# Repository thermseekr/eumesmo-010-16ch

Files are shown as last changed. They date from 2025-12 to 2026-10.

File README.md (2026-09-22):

# eumesmo-010-16ch
ESP32 based board with 16x 0-10V analog output, for light dimming control. The board has a DC-DC Converter and an I2C isolator to keep the digital and analog domains fully separated.

The board is compatible with the SP7 DIN rail system from Metaltex.

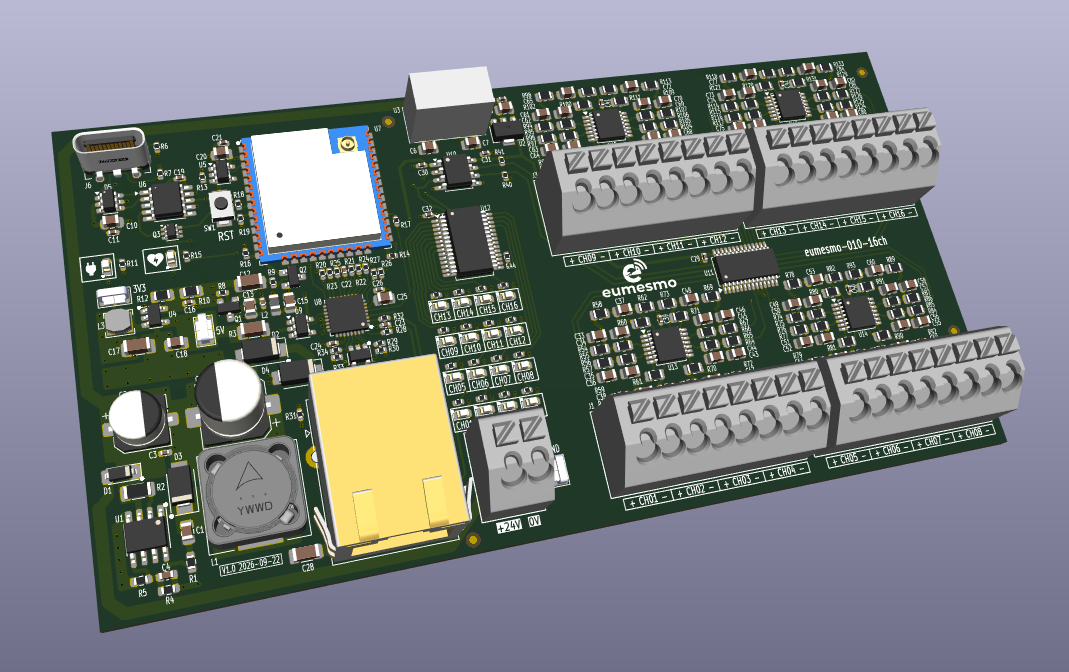
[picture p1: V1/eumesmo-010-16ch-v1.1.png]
eumesmo-010-16ch


## VERSION HISTORY
2026-09-22 V1.0 - RJ45 jack and terminal blocks repositioned inwards the board to make space for the PCB holder. ETH tracks rerouted for better EMC.

2026-07-02 V1.0 - Initial release.

## LICENSE

This project is licensed under the [Creative Commons BY-NC 4.0 License](https://creativecommons.org/licenses/by-nc/4.0/).
Commercial use is not permitted without prior written consent. See the [LICENSE.txt](LICENSE.txt) file for details.

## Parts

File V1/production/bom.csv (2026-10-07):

Designator | Footprint | Quantity | Value | LCSC Part #
C1, C33, C34, C35, C36, C43, C44, C45, C46, C49, C50, C51, C52, C55, C56, C57, C58, C61, C62, C63, C64, C67, C68, C69, C70, C73, C74, C75, C76, C79, C80, C81, C82 | 0805 | 33 | 100nF/100V | C28233
C10, C13, C15, C18, C20, C7 | 0805 | 6 | 10uF/25V | C15850
C11, C14, C19, C21, C22, C23, C24, C27, C29, C3, C30, C31, C32, C39, C40, C41, C42, C9 | 0402 | 18 | 100nF/50V | C307331
C12, C17 | 1206 | 2 | 22uF/10V | C5672
C16 | 0402 | 1 | 22pF/50V | C1555
C2 | CP_Elec_6.3x5.4 | 1 | 47uF/35V | C129415
C25, C6, C8 | 0805 | 3 | 1uF/50V | C28323
C26 | 0402 | 1 | 470pF/50V | C1537
C28 | 1206 | 1 | 1nF/2kV | C9196
C37, C38, C47, C48, C53, C54, C59, C60, C65, C66, C71, C72, C77, C78, C83, C84 | 0805 | 16 | 100pF/50V | C1790
C4 | 0603 | 1 | 12pF/50V | C38523
C5 | CP_Elec_8x10.5 | 1 | 470uF/16V | C96179
D1 | D_SOD-123 | 1 | SM4007PL | C64898
D10, D11, D12, D13, D14, D15, D16, D17, D18, D19, D20, D21, D22, D23, D24, D6, D7, D9 | 0603 | 18 | ORANGE/0603 | C2987557
D2, D4 | D_SMA | 2 | SS34 | C8678
D3 | D_SMA | 1 | SS510 | C65010
D5 | SOT-23-6 | 1 | USBLC6-2SC6 | C7519
D8 | SOT-23-5 | 1 | ESDS314DBV | C1847859
J1, J2, J3, J4 | TerminalBlock_Wago_250-208_1x08_P3.5mm_45Degree | 4 | 250-208 | C2833587
J5 | TerminalBlock_Wago_250-202_1x02_P3.5mm_45Degree | 1 | 250-202 | C2765061
J6 | USB_C_Receptacle_ShouHan_TYPE-C-16PLT-H10.0 | 1 | USB_C_Receptacle_USB2.0 | C3151749
J7 | RJ45_HanRun_HR915340A | 1 | ETHERNET | C6674467
L1 | L_12x12mm_H6mm | 1 | 33uH 2,1A | C169386
L2 | 0805 | 1 | 2A 600R | C139168
L3 | L_3x3mm_H1.5mm | 1 | 2,2uH 1,5A | C370424
Q1 | SOT-23 | 1 | WPM2015-3/TR | C558305
Q2 | SOT-23 | 1 | MMUN2211LT3G | C150229
Q3 | SOT-363_SC-70-6 | 1 | UMH3N | C62892
R1 | 0603 | 1 | 5,1R/100mW | C25197
R10 | 0805 | 1 | 100k/125mW | C149504
R100, R101, R110, R111, R120, R121, R130, R131, R60, R61, R70, R71, R80, R81, R90, R91 | 0805 | 16 | 11k/125mW | C17429
R102, R103, R104, R105, R106, R107, R112, R113, R114, R115, R116, R117, R122, R123, R124, R125, R126, R127, R132, R133, R54, R55, R56, R57, R62, R63, R64, R65, R66, R67, R72, R73, R74, R75, R76, R77, R82, R83, R84, R85, R86, R87, R92, R93, R94, R95, R96, R97 | 0805 | 48 | 10k/125mW | C17414
R108, R109, R118, R119, R128, R129, R58, R59, R68, R69, R78, R79, R88, R89, R98, R99 | 0805 | 16 | 47R/125mW | C17714
R11, R15, R35, R36, R37, R38, R39, R42, R43, R45, R46, R47, R48, R49, R50, R51, R52, R53 | 0402 | 18 | 680R | C25130
R12 | 0805 | 1 | 22,1k/125mW | C17552
R13, R14, R16, R8 | 0402 | 4 | 10k | C25744
R17 | 0402 | 1 | 33R | C25105
R18, R19, R21, R22, R23, R24, R25, R26, R27, R40, R41 | 0402 | 11 | 2,2k | C25879
R2 | 1206 | 1 | 30mR/333mW | C473665
R20 | 0402 | 1 | 1.5k | C25867
R28 | 0402 | 1 | 12,1k | C281773
R29, R30, R33, R34 | 0402 | 4 | 49,9R | C25120
R3 | 1206 | 1 | 0,1R | C309528
R31, R32 | 0402 | 2 | 330R | C25104
R4 | 0603 | 1 | 300k/100mW | C23024
R44, R9 | 0402 | 2 | 1k | C11702
R5 | 0603 | 1 | 52,3k/100mW | C23198
R6, R7 | 0402 | 2 | 5,1k | C105872
SW1 | SW_SPST_Xunpu_TS1088AR02016 | 1 | RESET | C720477
TP2, TP3, TP8 | TestPoint_Keystone_5019_Miniature | 3 | TP5019 | C238131
U1 | SOIC-8-1EP_3.9x4.9mm_P1.27mm_EP2.41x3.81mm_ThermalVias | 1 | TX4138 | C329267
U10 | SOIC-8_3.9x4.9mm_P1.27mm | 1 | ISO1540 | C179739
U11 | TSSOP-28_4.4x9.7mm_P0.65mm | 1 | PCA9685PW | C2678753
U12 | SSOP-28_5.3x10.2mm_P0.65mm | 1 | MCP23017 | C506653
U13, U14, U15, U16 | TSSOP-14_4.4x5mm_P0.65mm | 4 | TLV274 | C9914
U2 | SOT-89-3 | 1 | L78L05_SOT89 | C42738
U3 | Ylptec BxxxxS-1WR3 | 1 | B2412S-1WR3 | C5369469
U4 | SOT-23-5_Shorter_Pins | 1 | SY8089A1AAC | C479074
U5, U9 | SOT-23-5 | 2 | TPS3820-33 | C130064
U6 | SSOP-10-1EP_3.9x4.9mm_P1mm_EP2.1x3.3mm | 1 | CH340K | C968586
U7 | ESP32-WROOM-32U | 1 | ESP32-WROOM-32UE-N16 | C701346
U8 | QFN-32-1EP_5x5mm_P0.5mm_EP3.3x3.3mm_ThermalVias | 1 | LAN8710A | C46185

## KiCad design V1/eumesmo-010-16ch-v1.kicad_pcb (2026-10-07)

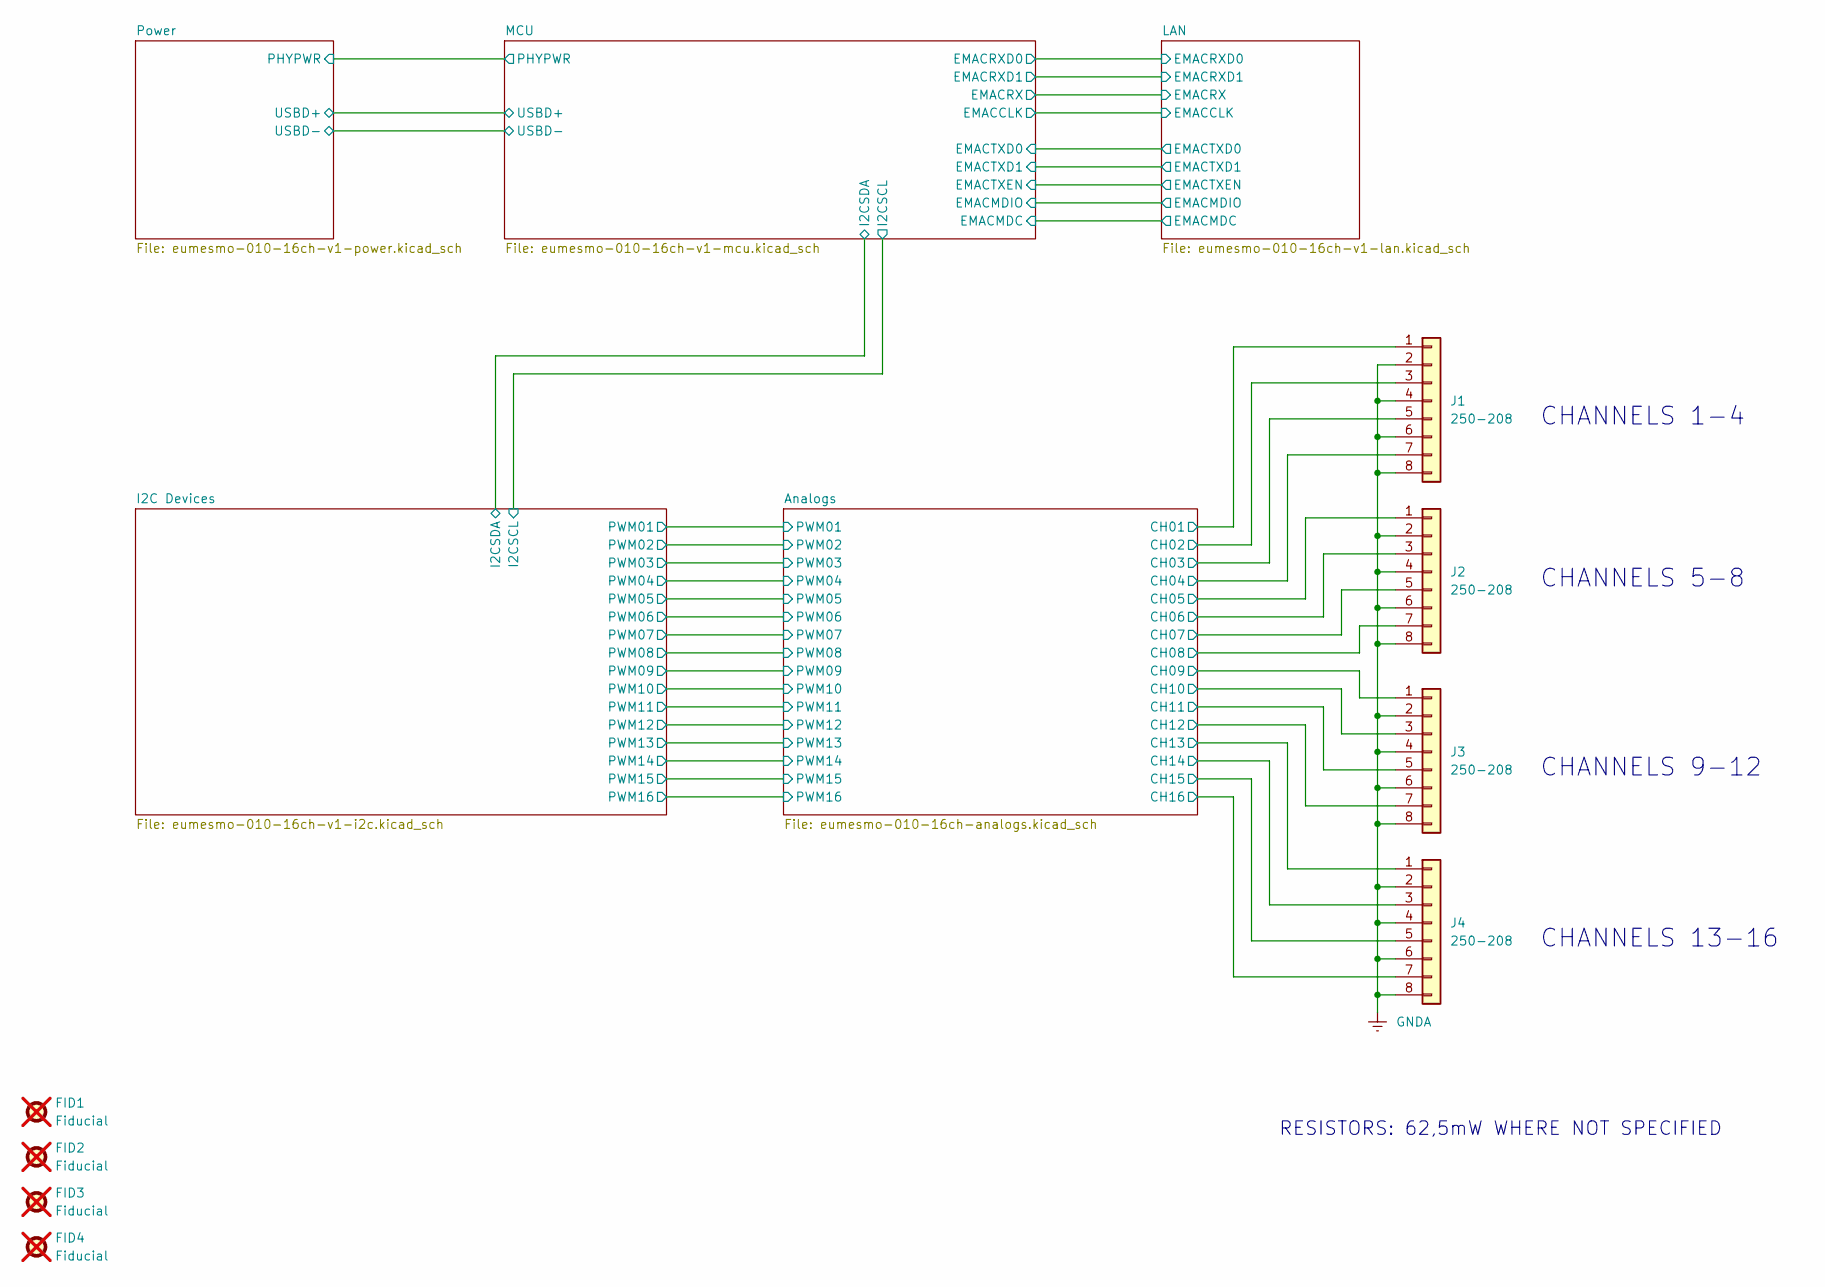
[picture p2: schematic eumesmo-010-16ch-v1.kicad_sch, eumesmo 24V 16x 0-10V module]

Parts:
FID1, FID2, FID3, FID4: Fiducial; Fiducial_1mm_Mask2mm; not fitted
J1, J2, J3, J4: 250-208; TerminalBlock_Wago_250-208_1x08_P3.5mm_45Degree; Mfr PN 250-208; LCSC Part # C2833587

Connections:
/Analogs/CH01: J1.1; also elsewhere on the board
/Analogs/CH02: J1.3; also elsewhere on the board
/Analogs/CH03: J1.5; also elsewhere on the board
/Analogs/CH04: J1.7; also elsewhere on the board
/Analogs/CH05: J2.1; also elsewhere on the board
/Analogs/CH06: J2.3; also elsewhere on the board
/Analogs/CH07: J2.5; also elsewhere on the board
/Analogs/CH08: J2.7; also elsewhere on the board
/Analogs/CH09: J3.1; also elsewhere on the board
/Analogs/CH10: J3.3; also elsewhere on the board
/Analogs/CH11: J3.5; also elsewhere on the board
/Analogs/CH12: J3.7; also elsewhere on the board
/Analogs/CH13: J4.1; also elsewhere on the board
/Analogs/CH14: J4.3; also elsewhere on the board
/Analogs/CH15: J4.5; also elsewhere on the board
/Analogs/CH16: J4.7; also elsewhere on the board
GNDA: J1.2, J1.4, J1.6, J1.8, J2.2, J2.4, J2.6, J2.8, J3.2, J3.4, J3.6, J3.8, J4.2, J4.4, J4.6, J4.8; also elsewhere on the board

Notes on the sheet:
CHANNELS 9-12
CHANNELS 13-16
RESISTORS: 62,5mW WHERE NOT SPECIFIED
CHANNELS 1-4
CHANNELS 5-8

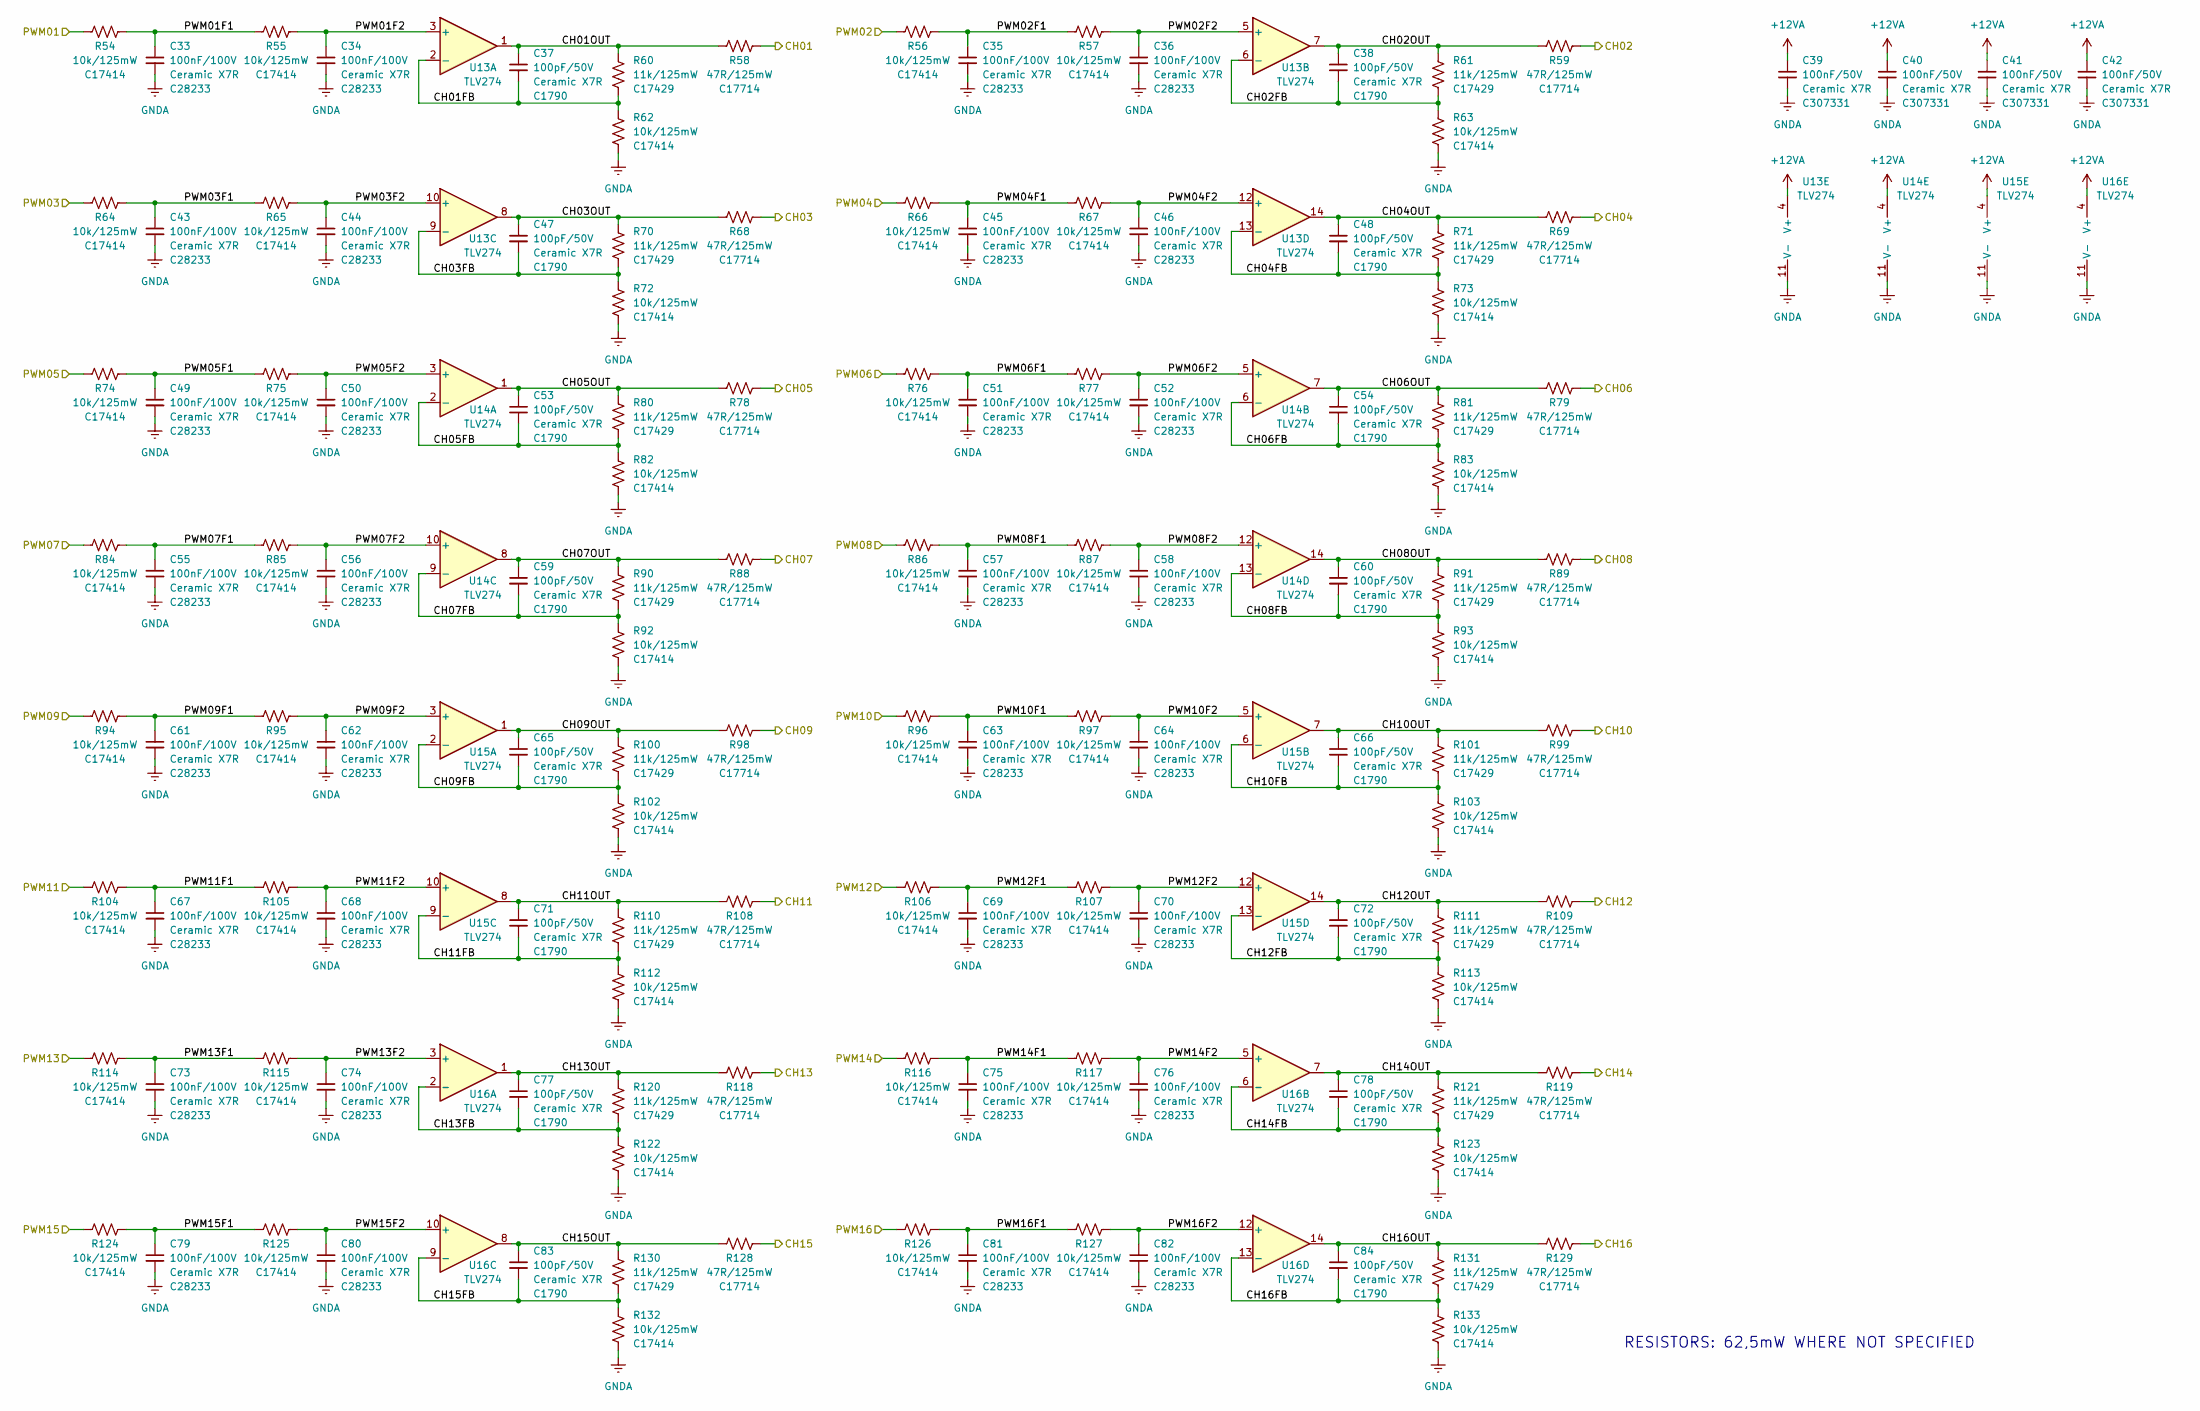
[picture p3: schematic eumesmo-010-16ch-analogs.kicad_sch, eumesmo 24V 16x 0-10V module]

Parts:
C33, C34, C35, C36, C43, C44, C45, C46, C49, C50, C51, C52, C55, C56, C57, C58, C61, C62, C63, C64, C67, C68, C69, C70, C73, C74, C75, C76, C79, C80, C81, C82: 100nF/100V; C_0805_2012Metric; Mfr PN CL21B104KCFNNNE; LCSC Part # C28233
C37, C38, C47, C48, C53, C54, C59, C60, C65, C66, C71, C72, C77, C78, C83, C84: 100pF/50V; C_0805_2012Metric; Mfr PN CL21C101JBANNNC; LCSC Part # C1790
C39, C40, C41, C42: 100nF/50V; C_0402_1005Metric; Mfr PN CL05B104KB54PNC; LCSC Part # C307331
R54, R55, R56, R57, R62, R63, R64, R65, R66, R67, R72, R73, R74, R75, R76, R77, R82, R83, R84, R85, R86, R87, R92, R93, R94, R95, R96, R97, R102, R103, R104, R105, R106, R107, R112, R113, R114, R115, R116, R117, R122, R123, R124, R125, R126, R127, R132, R133: 10k/125mW; R_0805_2012Metric; Mfr PN 0805W8F1002T5E; LCSC Part # C17414
R58, R59, R68, R69, R78, R79, R88, R89, R98, R99, R108, R109, R118, R119, R128, R129: 47R/125mW; R_0805_2012Metric; Mfr PN 0805W8F470JT5E; LCSC Part # C17714
R60, R61, R70, R71, R80, R81, R90, R91, R100, R101, R110, R111, R120, R121, R130, R131: 11k/125mW; R_0805_2012Metric; Mfr PN 0805W8F1102T5E; LCSC Part # C17429
U13, U14, U15, U16: TLV274; TSSOP-14_4.4x5mm_P0.65mm; Mfr PN TLV274; LCSC Part # C9914

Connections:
+12VA: C39.1, C40.1, C41.1, C42.1, U13.4 (V+), U14.4 (V+), U15.4 (V+), U16.4 (V+); also elsewhere on the board
/Analogs/CH01: R58.2; also elsewhere on the board
/Analogs/CH01FB: C37.2, R60.1, R62.2, U13.2 (-)
/Analogs/CH01OUT: C37.1, R58.1, R60.2, U13.1
/Analogs/CH02: R59.2; also elsewhere on the board
/Analogs/CH02FB: C38.2, R61.1, R63.2, U13.6 (-)
/Analogs/CH02OUT: C38.1, R59.1, R61.2, U13.7
/Analogs/CH03: R68.2; also elsewhere on the board
/Analogs/CH03FB: C47.2, R70.1, R72.2, U13.9 (-)
/Analogs/CH03OUT: C47.1, R68.1, R70.2, U13.8
/Analogs/CH04: R69.2; also elsewhere on the board
/Analogs/CH04FB: C48.2, R71.1, R73.2, U13.13 (-)
/Analogs/CH04OUT: C48.1, R69.1, R71.2, U13.14
/Analogs/CH05: R78.2; also elsewhere on the board
/Analogs/CH05FB: C53.2, R80.1, R82.2, U14.2 (-)
/Analogs/CH05OUT: C53.1, R78.1, R80.2, U14.1
/Analogs/CH06: R79.2; also elsewhere on the board
/Analogs/CH06FB: C54.2, R81.1, R83.2, U14.6 (-)
/Analogs/CH06OUT: C54.1, R79.1, R81.2, U14.7
/Analogs/CH07: R88.2; also elsewhere on the board
/Analogs/CH07FB: C59.2, R90.1, R92.2, U14.9 (-)
/Analogs/CH07OUT: C59.1, R88.1, R90.2, U14.8
/Analogs/CH08: R89.2; also elsewhere on the board
/Analogs/CH08FB: C60.2, R91.1, R93.2, U14.13 (-)
/Analogs/CH08OUT: C60.1, R89.1, R91.2, U14.14
/Analogs/CH09: R98.2; also elsewhere on the board
/Analogs/CH09FB: C65.2, R100.1, R102.2, U15.2 (-)
/Analogs/CH09OUT: C65.1, R98.1, R100.2, U15.1
/Analogs/CH10: R99.2; also elsewhere on the board
/Analogs/CH10FB: C66.2, R101.1, R103.2, U15.6 (-)
/Analogs/CH10OUT: C66.1, R99.1, R101.2, U15.7
/Analogs/CH11: R108.2; also elsewhere on the board
/Analogs/CH11FB: C71.2, R110.1, R112.2, U15.9 (-)
/Analogs/CH11OUT: C71.1, R108.1, R110.2, U15.8
/Analogs/CH12: R109.2; also elsewhere on the board
/Analogs/CH12FB: C72.2, R111.1, R113.2, U15.13 (-)
/Analogs/CH12OUT: C72.1, R109.1, R111.2, U15.14
/Analogs/CH13: R118.2; also elsewhere on the board
/Analogs/CH13FB: C77.2, R120.1, R122.2, U16.2 (-)
/Analogs/CH13OUT: C77.1, R118.1, R120.2, U16.1
/Analogs/CH14: R119.2; also elsewhere on the board
/Analogs/CH14FB: C78.2, R121.1, R123.2, U16.6 (-)
/Analogs/CH14OUT: C78.1, R119.1, R121.2, U16.7
/Analogs/CH15: R128.2; also elsewhere on the board
/Analogs/CH15FB: C83.2, R130.1, R132.2, U16.9 (-)
/Analogs/CH15OUT: C83.1, R128.1, R130.2, U16.8
/Analogs/CH16: R129.2; also elsewhere on the board
/Analogs/CH16FB: C84.2, R131.1, R133.2, U16.13 (-)
/Analogs/CH16OUT: C84.1, R129.1, R131.2, U16.14
/Analogs/PWM01: R54.1; also elsewhere on the board
/Analogs/PWM01F1: C33.1, R54.2, R55.1
/Analogs/PWM01F2: C34.1, R55.2, U13.3 (+)
/Analogs/PWM02: R56.1; also elsewhere on the board
/Analogs/PWM02F1: C35.1, R56.2, R57.1
/Analogs/PWM02F2: C36.1, R57.2, U13.5 (+)
/Analogs/PWM03: R64.1; also elsewhere on the board
/Analogs/PWM03F1: C43.1, R64.2, R65.1
/Analogs/PWM03F2: C44.1, R65.2, U13.10 (+)
/Analogs/PWM04: R66.1; also elsewhere on the board
/Analogs/PWM04F1: C45.1, R66.2, R67.1
/Analogs/PWM04F2: C46.1, R67.2, U13.12 (+)
/Analogs/PWM05: R74.1; also elsewhere on the board
/Analogs/PWM05F1: C49.1, R74.2, R75.1
/Analogs/PWM05F2: C50.1, R75.2, U14.3 (+)
/Analogs/PWM06: R76.1; also elsewhere on the board
/Analogs/PWM06F1: C51.1, R76.2, R77.1
/Analogs/PWM06F2: C52.1, R77.2, U14.5 (+)
/Analogs/PWM07: R84.1; also elsewhere on the board
/Analogs/PWM07F1: C55.1, R84.2, R85.1
/Analogs/PWM07F2: C56.1, R85.2, U14.10 (+)
/Analogs/PWM08: R86.1; also elsewhere on the board
/Analogs/PWM08F1: C57.1, R86.2, R87.1
/Analogs/PWM08F2: C58.1, R87.2, U14.12 (+)
/Analogs/PWM09: R94.1; also elsewhere on the board
/Analogs/PWM09F1: C61.1, R94.2, R95.1
/Analogs/PWM09F2: C62.1, R95.2, U15.3 (+)
/Analogs/PWM10: R96.1; also elsewhere on the board
/Analogs/PWM10F1: C63.1, R96.2, R97.1
/Analogs/PWM10F2: C64.1, R97.2, U15.5 (+)
/Analogs/PWM11: R104.1; also elsewhere on the board
/Analogs/PWM11F1: C67.1, R104.2, R105.1
/Analogs/PWM11F2: C68.1, R105.2, U15.10 (+)
/Analogs/PWM12: R106.1; also elsewhere on the board
/Analogs/PWM12F1: C69.1, R106.2, R107.1
/Analogs/PWM12F2: C70.1, R107.2, U15.12 (+)
/Analogs/PWM13: R114.1; also elsewhere on the board
/Analogs/PWM13F1: C73.1, R114.2, R115.1
/Analogs/PWM13F2: C74.1, R115.2, U16.3 (+)
/Analogs/PWM14: R116.1; also elsewhere on the board
/Analogs/PWM14F1: C75.1, R116.2, R117.1
/Analogs/PWM14F2: C76.1, R117.2, U16.5 (+)
/Analogs/PWM15: R124.1; also elsewhere on the board
/Analogs/PWM15F1: C79.1, R124.2, R125.1
/Analogs/PWM15F2: C80.1, R125.2, U16.10 (+)
/Analogs/PWM16: R126.1; also elsewhere on the board
/Analogs/PWM16F1: C81.1, R126.2, R127.1
/Analogs/PWM16F2: C82.1, R127.2, U16.12 (+)
GNDA: C33.2, C34.2, C35.2, C36.2, C39.2, C40.2, C41.2, C42.2, C43.2, C44.2, C45.2, C46.2, C49.2, C50.2, C51.2, C52.2, C55.2, C56.2, C57.2, C58.2, C61.2, C62.2, C63.2, C64.2, C67.2, C68.2, C69.2, C70.2, C73.2, C74.2, C75.2, C76.2, C79.2, C80.2, C81.2, C82.2, R62.1, R63.1, R72.1, R73.1, R82.1, R83.1, R92.1, R93.1, R102.1, R103.1, R112.1, R113.1, R122.1, R123.1, R132.1, R133.1, U13.11 (V-), U14.11 (V-), U15.11 (V-), U16.11 (V-); also elsewhere on the board

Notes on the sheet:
RESISTORS: 62,5mW WHERE NOT SPECIFIED

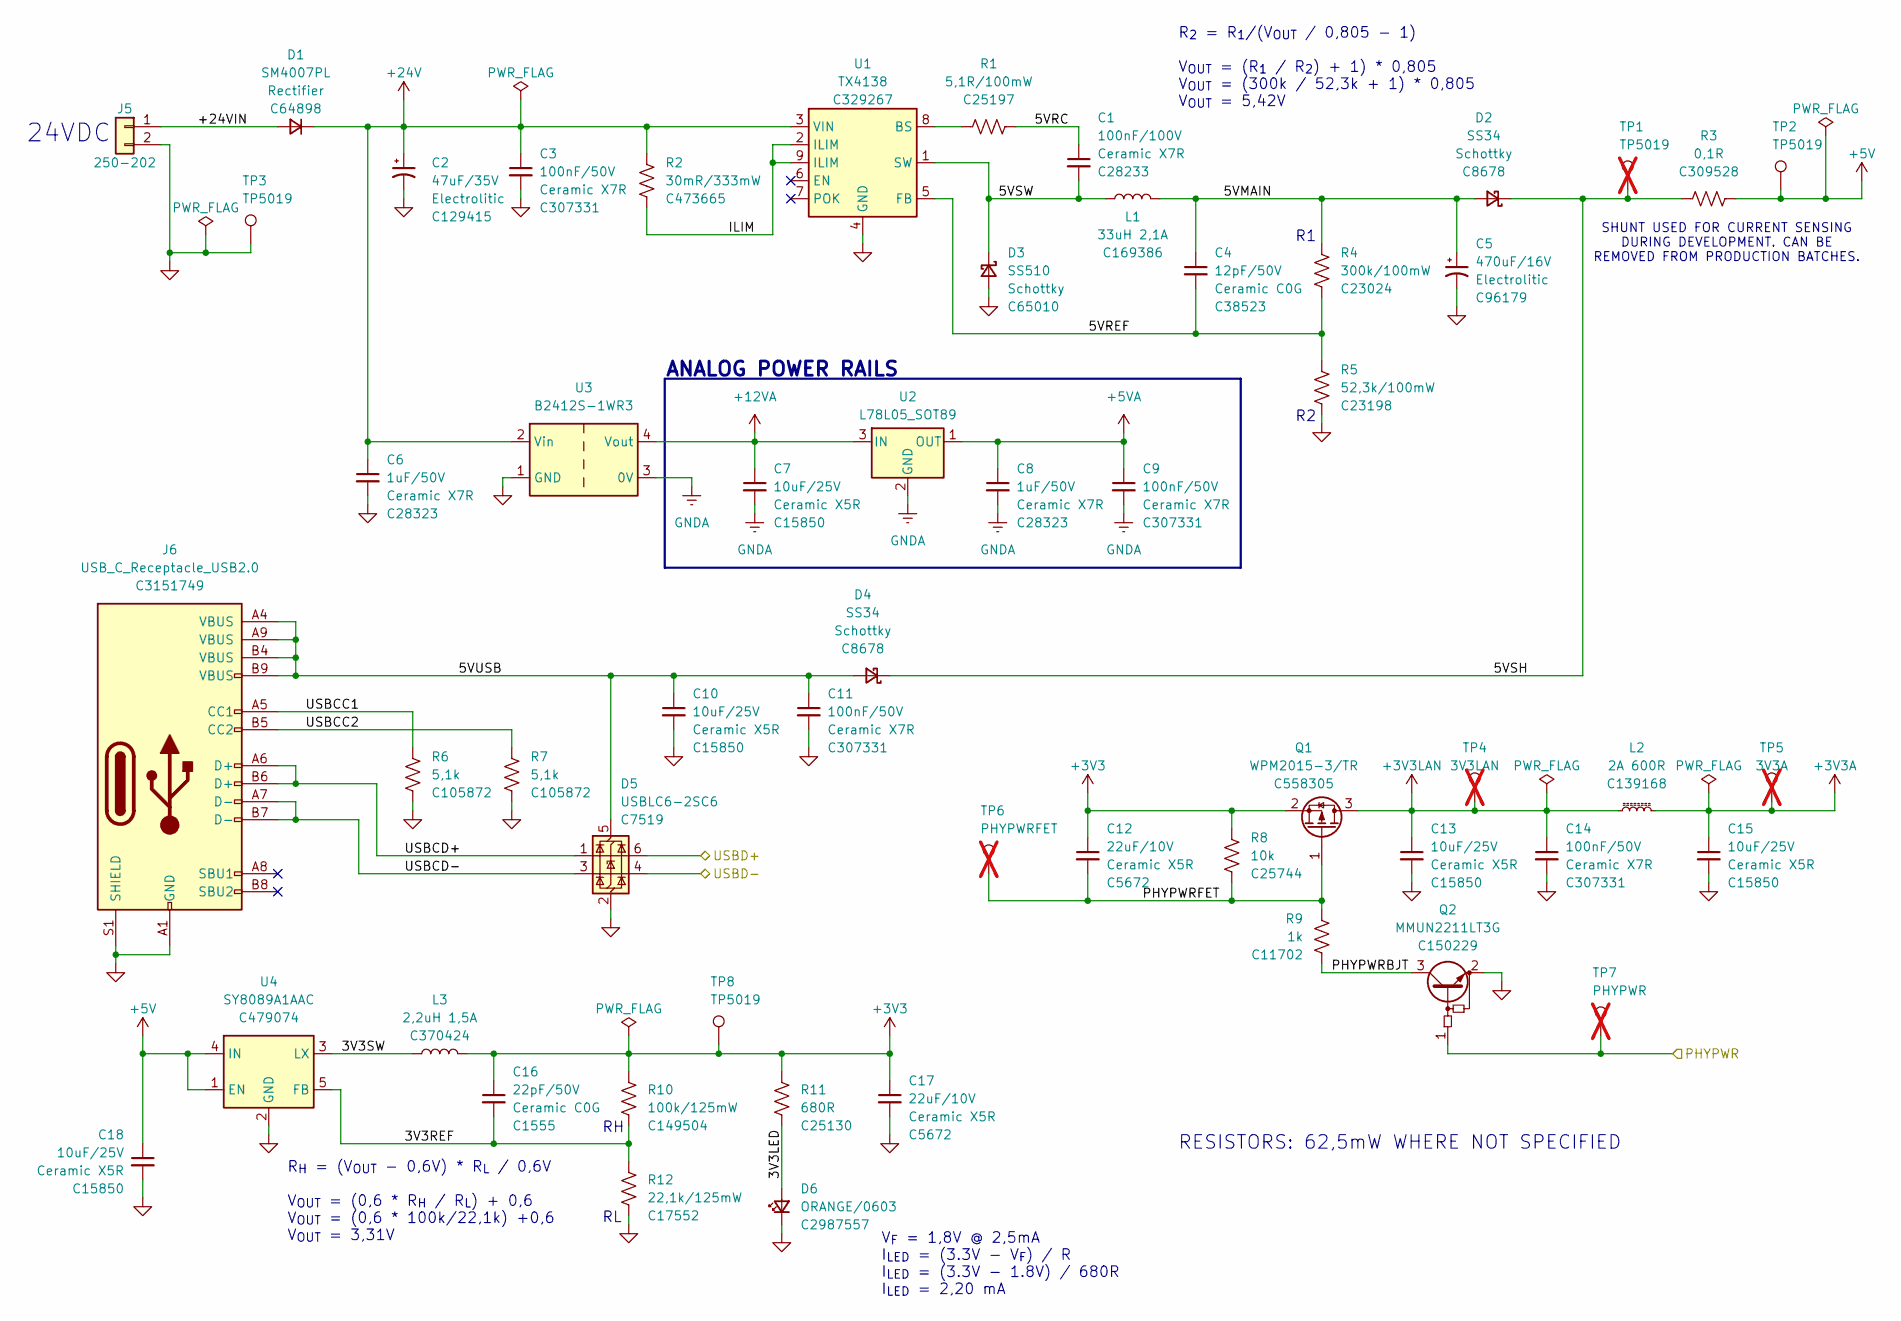
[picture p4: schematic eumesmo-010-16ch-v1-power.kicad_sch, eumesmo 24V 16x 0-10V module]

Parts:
C1: 100nF/100V; C_0805_2012Metric; Mfr PN CL21B104KCFNNNE; LCSC Part # C28233
C2: 47uF/35V; CP_Elec_6.3x5.4; Mfr PN CK1V470M-CRE54; LCSC Part # C129415
C3, C9, C11, C14: 100nF/50V; C_0402_1005Metric; Mfr PN CL05B104KB54PNC; LCSC Part # C307331
C4: 12pF/50V; C_0603_1608Metric; Mfr PN CL10C120JB8NNNC; LCSC Part # C38523
C5: 470uF/16V; CP_Elec_8x10.5; Mfr PN CS1C471M-CRF10; LCSC Part # C96179
C6, C8: 1uF/50V; C_0805_2012Metric; Mfr PN CL21B105KBFNNNE; LCSC Part # C28323
C7, C10, C13, C15, C18: 10uF/25V; C_0805_2012Metric; Mfr PN CL21A106KAYNNNE; LCSC Part # C15850
C12, C17: 22uF/10V; C_1206_3216Metric; Mfr PN CL31A226KPHNNNE; LCSC Part # C5672
C16: 22pF/50V; C_0402_1005Metric; Mfr PN 0402CG220J500NT; LCSC Part # C1555
D1: SM4007PL; D_SOD-123; Mfr PN SM4007PL; LCSC Part # C64898
D2, D4: SS34; D_SMA; Mfr PN SS34; LCSC Part # C8678
D3: SS510; D_SMA; Mfr PN SS510; LCSC Part # C65010
D5: USBLC6-2SC6; SOT-23-6; Mfr PN USBLC6-2SC6; LCSC Part # C7519
D6: ORANGE/0603; LED_0603_1608Metric; Mfr PN 19-217/S2C-AL1M2VY/6T; LCSC Part # C2987557
J5: 250-202; TerminalBlock_Wago_250-202_1x02_P3.5mm_45Degree; Mfr PN 250-202; LCSC Part # C2765061
J6: USB_C_Receptacle_USB2.0; USB_C_Receptacle_ShouHan_TYPE-C-16PLT-H10.0; Mfr PN TYPE-C 16PLT-H10.0; LCSC Part # C3151749
L1: 33uH 2,1A; L_12x12mm_H6mm; Mfr PN SWRB1205S-330MT; LCSC Part # C169386
L2: 2A 600R; L_0805_2012Metric; Mfr PN CBM201209U601T; LCSC Part # C139168
L3: 2,2uH 1,5A; L_3x3mm_H1.5mm; Mfr PN SPH3015H2R2MT; LCSC Part # C370424
Q1: WPM2015-3/TR; SOT-23; Mfr PN WPM2015-3/TR; LCSC Part # C558305
Q2: MMUN2211LT3G; SOT-23; Mfr PN MMUN2211LT3G; LCSC Part # C150229
R1: 5,1R/100mW; R_0603_1608Metric; Mfr PN 0603WAF510KT5E; LCSC Part # C25197
R2: 30mR/333mW; R_1206_3216Metric; Mfr PN 1206W3F300MT5E; LCSC Part # C473665
R3: 0,1R; C_1206_3216Metric; Mfr PN PE1206FRF470R1L; LCSC Part # C309528
R4: 300k/100mW; R_0603_1608Metric; Mfr PN 0603WAF3003T5E; LCSC Part # C23024
R5: 52,3k/100mW; R_0603_1608Metric; Mfr PN 0603WAF5232T5E; LCSC Part # C23198
R6, R7: 5,1k; R_0402_1005Metric; Mfr PN RC0402FR-075K1L; LCSC Part # C105872
R8: 10k; R_0402_1005Metric; Mfr PN 0402WGF1002TCE; LCSC Part # C25744
R9: 1k; R_0402_1005Metric; Mfr PN 0402WGF1001TCE; LCSC Part # C11702
R10: 100k/125mW; R_0805_2012Metric; Mfr PN 0805W8F1003T5E; LCSC Part # C149504
R11: 680R; R_0402_1005Metric; Mfr PN 0402WGF6800TCE; LCSC Part # C25130
R12: 22,1k/125mW; R_0805_2012Metric; Mfr PN 0805W8F2212T5E; LCSC Part # C17552
TP1: TP5019; TestPoint_Keystone_5019_Miniature; Mfr PN 5019; LCSC Part # C238131; not fitted
TP2, TP3, TP8: TP5019; TestPoint_Keystone_5019_Miniature; Mfr PN 5019; LCSC Part # C238131
TP4: 3V3LAN; TestPoint_Pad_D1.5mm; not fitted
TP5: 3V3A; TestPoint_Pad_D1.5mm; not fitted
TP6: PHYPWRFET; TestPoint_Pad_D1.5mm; not fitted
TP7: PHYPWR; TestPoint_Pad_D1.5mm; not fitted
U1: TX4138; SOIC-8-1EP_3.9x4.9mm_P1.27mm_EP2.41x3.81mm_ThermalVias; Mfr PN TX4138; LCSC Part # C329267
U2: L78L05_SOT89; SOT-89-3; Mfr PN L78L05ABUTR; LCSC Part # C42738
U3: B2412S-1WR3; Ylptec BxxxxS-1WR3; Mfr PN B2412S-1WR3; LCSC Part # C5369469
U4: SY8089A1AAC; SOT-23-5_Shorter_Pins; Mfr PN SY8089A1AAC; LCSC Part # C479074

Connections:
+3V3: C12.1, C16.1, C17.1, L3.2, Q1.2 (S), R8.1, R10.1, R11.1, TP8.1 (1_1); also elsewhere on the board
+3V3A: C15.1, L2.2, TP5.1; also elsewhere on the board
+3V3LAN: C13.1, C14.1, L2.1, Q1.3 (D), TP4.1; also elsewhere on the board
+5V: C18.1, R3.1, TP2.1 (1_1), U4.1 (EN), U4.4 (IN)
+5VA: C8.1, C9.1, U2.1 (OUT); also elsewhere on the board
+12VA: C7.1, U2.3 (IN), U3.4 (Vout); also elsewhere on the board
+24V: C2.1, C3.1, C6.1, D1.1 (K), R2.1, U1.3 (VIN), U3.2 (Vin)
/MCU/PHYPWR: Q2.1 (B), TP7.1; also elsewhere on the board
/MCU/USBD+: D5.6 (I/O1); also elsewhere on the board
/MCU/USBD-: D5.4 (I/O2); also elsewhere on the board
/Power/3V3LED: D6.2 (A), R11.2
/Power/3V3REF: C16.2, R10.2, R12.1, U4.5 (FB)
/Power/3V3SW: L3.1, U4.3 (LX)
/Power/5VMAIN: C4.1, C5.1, D2.2 (A), L1.2, R4.1
/Power/5VRC: C1.1, R1.1
/Power/5VREF: C4.2, R4.2, R5.1, U1.5 (FB)
/Power/5VSH: D2.1 (K), D4.1 (K), R3.2, TP1.1
/Power/5VSW: C1.2, D3.1 (K), L1.1, U1.1 (SW)
/Power/5VUSB: C10.1, C11.1, D4.2 (A), D5.5 (VBUS), J6.A4 (VBUS), J6.A9 (VBUS), J6.B4 (VBUS), J6.B9 (VBUS)
/Power/+24VIN: D1.2 (A), J5.1
/Power/ILIM: R2.2, U1.2 (ILIM), U1.9 (ILIM)
/Power/PHYPWRBJT: Q2.3 (C), R9.1
/Power/PHYPWRFET: C12.2, Q1.1 (G), R8.2, R9.2, TP6.1
/Power/USBCC1: J6.A5 (CC1), R6.1
/Power/USBCC2: J6.B5 (CC2), R7.1
/Power/USBCD+: D5.1 (I/O1), J6.A6 (D+), J6.B6 (D+)
/Power/USBCD-: D5.3 (I/O2), J6.A7 (D-), J6.B7 (D-)
GND: C2.2, C3.2, C5.2, C6.2, C10.2, C11.2, C13.2, C14.2, C15.2, C17.2, C18.2, D3.2 (A), D5.2 (GND), D6.1 (K), J5.2, J6.A1 (GND), J6.A12 (GND), J6.B1 (GND), J6.B12 (GND), J6.S1 (SHIELD), Q2.2 (E), R5.2, R6.2, R7.2, R12.2, TP3.1 (1_1), U1.4 (GND), U3.1 (GND), U4.2 (GND); also elsewhere on the board
GNDA: C7.2, C8.2, C9.2, U2.2 (GND), U3.3 (0V); also elsewhere on the board
unnamed: R1.2, U1.8 (BS)

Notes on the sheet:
RESISTORS: 62,5mW WHERE NOT SPECIFIED
R_{H} = (V_{OUT} - 0,6V) * R_{L} / 0,6V V_{OUT} = (0,6 * R_{H} / R_{L}) + 0,6 V_{OUT} = (0,6 * 100k/22,1k) +0,6 V_{OUT} = 3,31V
R_{2} = R_{1}/(V_{OUT} / 0,805 - 1) V_{OUT} = (R_{1} / R_{2}) + 1) * 0,805 V_{OUT} = (300k / 52,3k + 1) * 0,805 V_{OUT} = 5,42V
SHUNT USED FOR CURRENT SENSING DURING DEVELOPMENT. CAN BE REMOVED FROM PRODUCTION BATCHES.
V_{F} = 1,8V @ 2,5mA I_{LED} = (3.3V - V_{F}) / R I_{LED} = (3.3V - 1.8V) / 680R I_{LED} = 2,20 mA
ANALOG POWER RAILS
24VDC

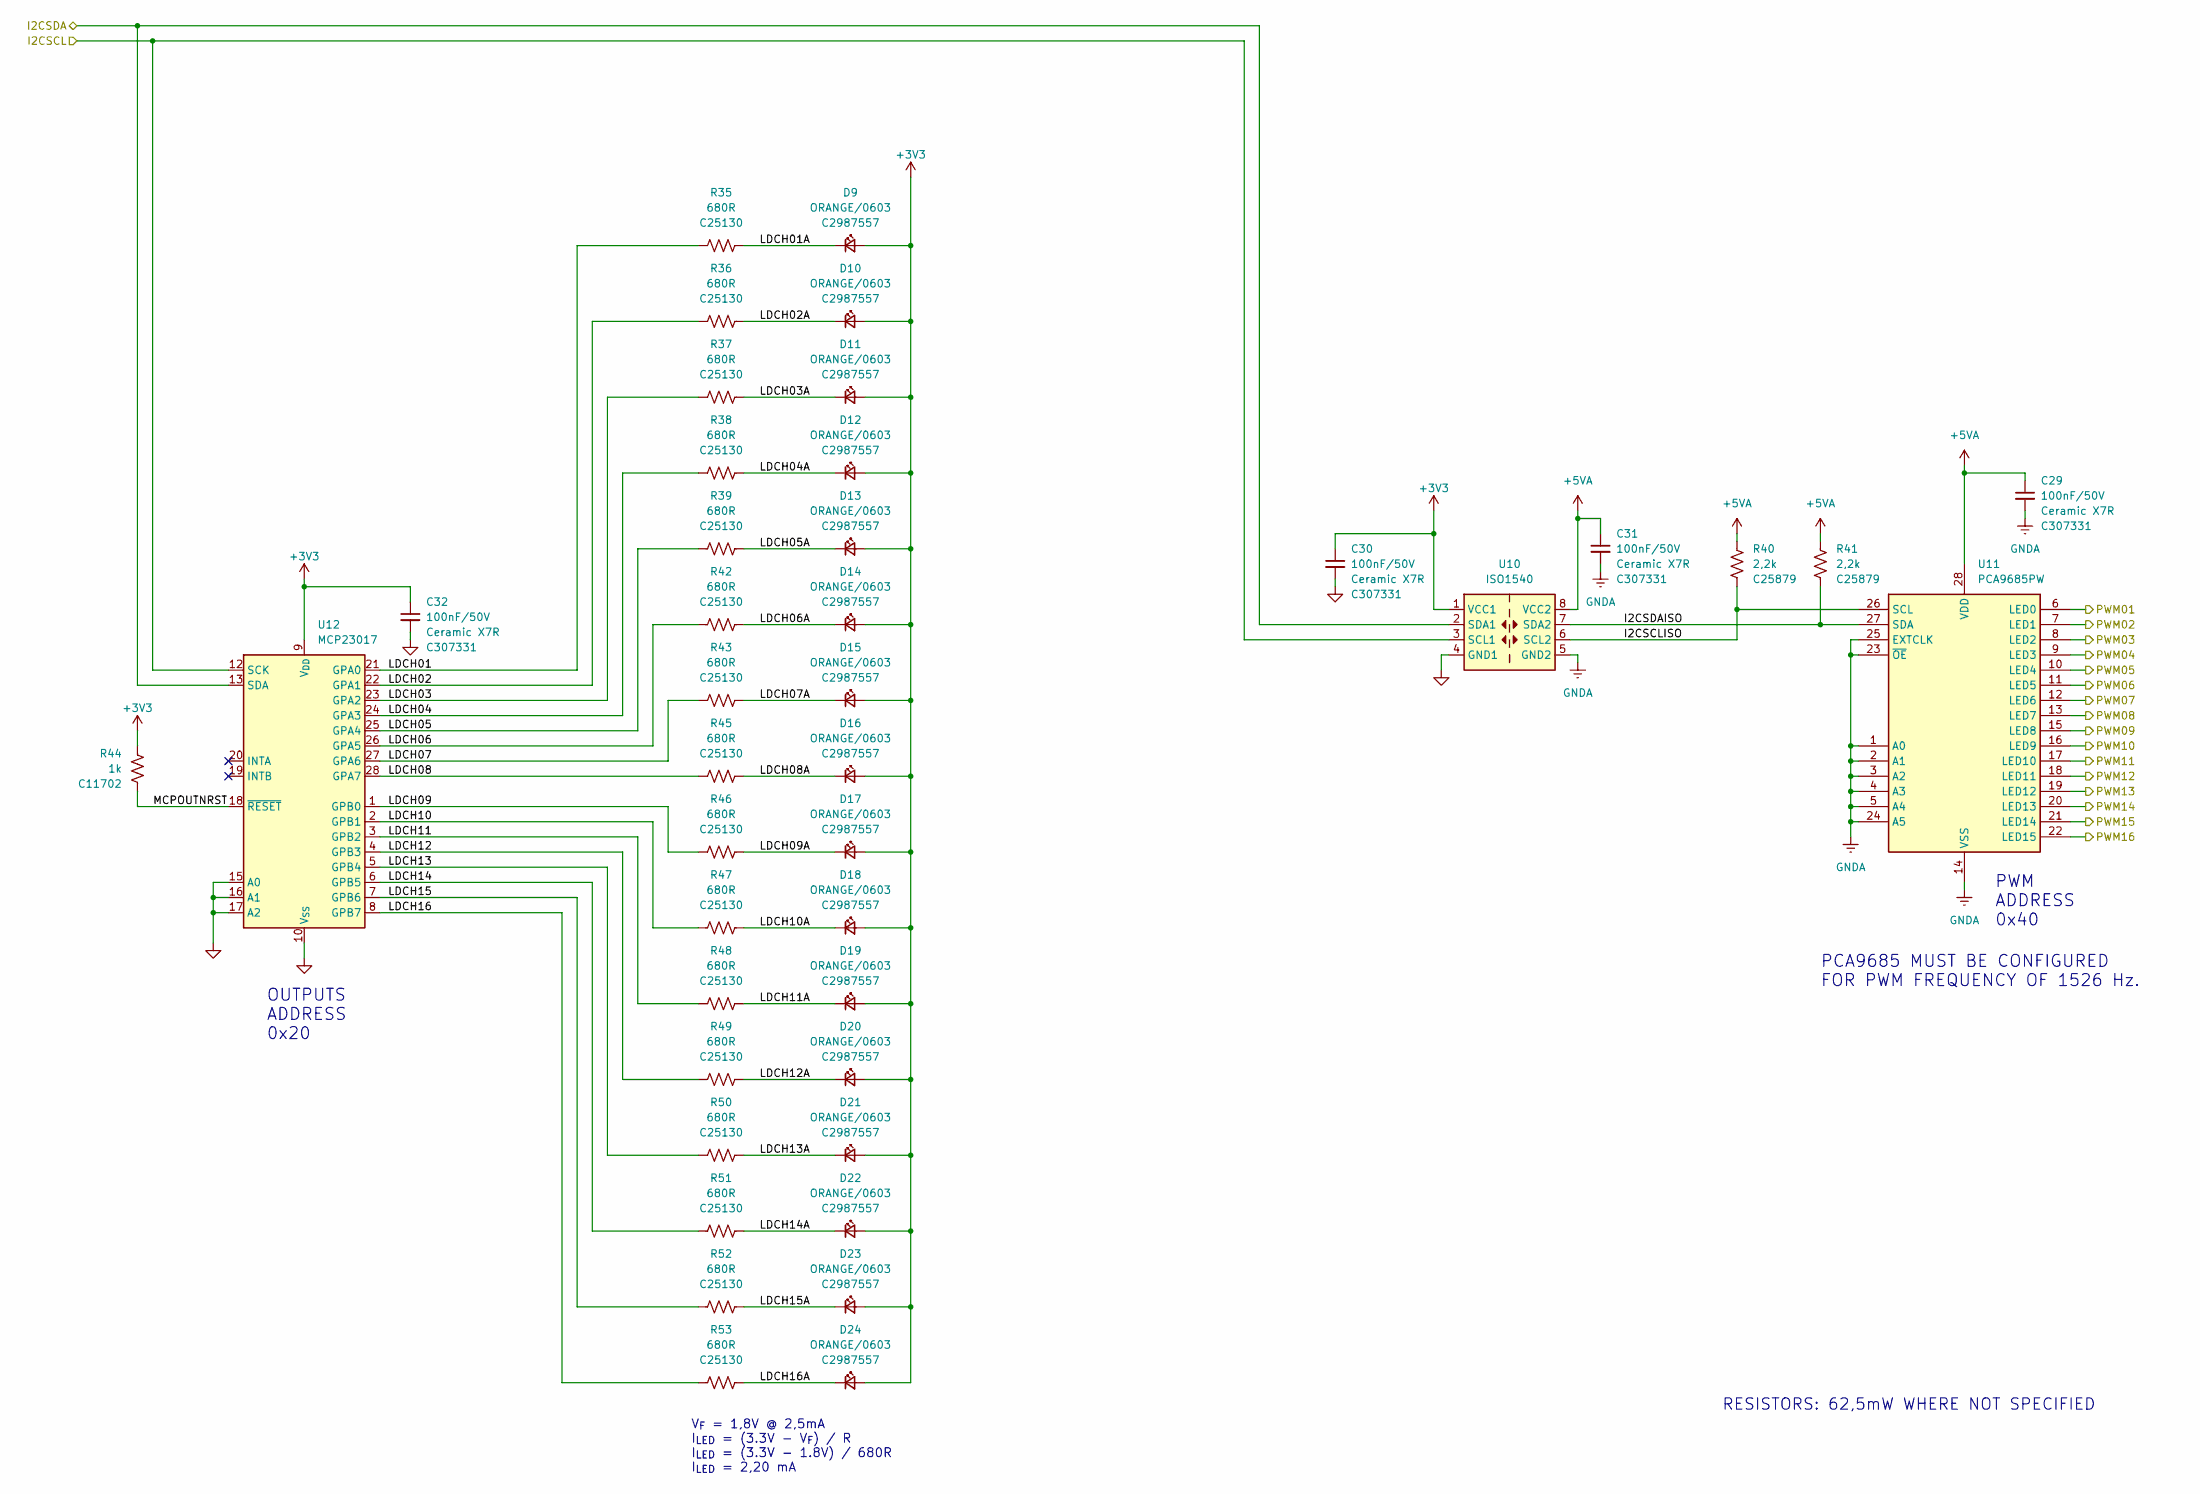
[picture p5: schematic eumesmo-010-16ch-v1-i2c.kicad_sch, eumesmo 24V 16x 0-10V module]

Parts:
C29, C30, C31, C32: 100nF/50V; C_0402_1005Metric; Mfr PN CL05B104KB54PNC; LCSC Part # C307331
D9, D10, D11, D12, D13, D14, D15, D16, D17, D18, D19, D20, D21, D22, D23, D24: ORANGE/0603; LED_0603_1608Metric; Mfr PN 19-217/S2C-AL1M2VY/6T; LCSC Part # C2987557
R35, R36, R37, R38, R39, R42, R43, R45, R46, R47, R48, R49, R50, R51, R52, R53: 680R; R_0402_1005Metric; Mfr PN 0402WGF6800TCE; LCSC Part # C25130
R40, R41: 2,2k; R_0402_1005Metric; Mfr PN 0402WGF2201TCE; LCSC Part # C25879
R44: 1k; R_0402_1005Metric; Mfr PN 0402WGF1001TCE; LCSC Part # C11702
U10: ISO1540; SOIC-8_3.9x4.9mm_P1.27mm; Mfr PN ISO1540DR; LCSC Part # C179739
U11: PCA9685PW; TSSOP-28_4.4x9.7mm_P0.65mm; Mfr PN PCA9685PW; LCSC Part # C2678753
U12: MCP23017; SSOP-28_5.3x10.2mm_P0.65mm; Mfr PN MCP23017-E/SS; LCSC Part # C506653

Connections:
+3V3: C30.1, C32.1, D9.2 (A), D10.2 (A), D11.2 (A), D12.2 (A), D13.2 (A), D14.2 (A), D15.2 (A), D16.2 (A), D17.2 (A), D18.2 (A), D19.2 (A), D20.2 (A), D21.2 (A), D22.2 (A), D23.2 (A), D24.2 (A), R44.1, U10.1 (VCC1), U12.9 (V_{DD}); also elsewhere on the board
+5VA: C29.1, C31.1, R40.1, R41.1, U10.8 (VCC2), U11.28 (VDD); also elsewhere on the board
/Analogs/PWM01: U11.6 (LED0); also elsewhere on the board
/Analogs/PWM02: U11.7 (LED1); also elsewhere on the board
/Analogs/PWM03: U11.8 (LED2); also elsewhere on the board
/Analogs/PWM04: U11.9 (LED3); also elsewhere on the board
/Analogs/PWM05: U11.10 (LED4); also elsewhere on the board
/Analogs/PWM06: U11.11 (LED5); also elsewhere on the board
/Analogs/PWM07: U11.12 (LED6); also elsewhere on the board
/Analogs/PWM08: U11.13 (LED7); also elsewhere on the board
/Analogs/PWM09: U11.15 (LED8); also elsewhere on the board
/Analogs/PWM10: U11.16 (LED9); also elsewhere on the board
/Analogs/PWM11: U11.17 (LED10); also elsewhere on the board
/Analogs/PWM12: U11.18 (LED11); also elsewhere on the board
/Analogs/PWM13: U11.19 (LED12); also elsewhere on the board
/Analogs/PWM14: U11.20 (LED13); also elsewhere on the board
/Analogs/PWM15: U11.21 (LED14); also elsewhere on the board
/Analogs/PWM16: U11.22 (LED15); also elsewhere on the board
/I2C Devices/I2CSCL: U10.3 (SCL1), U12.12 (SCK); also elsewhere on the board
/I2C Devices/I2CSCLISO: R40.2, U10.6 (SCL2), U11.26 (SCL)
/I2C Devices/I2CSDA: U10.2 (SDA1), U12.13 (SDA); also elsewhere on the board
/I2C Devices/I2CSDAISO: R41.2, U10.7 (SDA2), U11.27 (SDA)
/I2C Devices/LDCH01: R35.1, U12.21 (GPA0)
/I2C Devices/LDCH01A: D9.1 (K), R35.2
/I2C Devices/LDCH02: R36.1, U12.22 (GPA1)
/I2C Devices/LDCH02A: D10.1 (K), R36.2
/I2C Devices/LDCH03: R37.1, U12.23 (GPA2)
/I2C Devices/LDCH03A: D11.1 (K), R37.2
/I2C Devices/LDCH04: R38.1, U12.24 (GPA3)
/I2C Devices/LDCH04A: D12.1 (K), R38.2
/I2C Devices/LDCH05: R39.1, U12.25 (GPA4)
/I2C Devices/LDCH05A: D13.1 (K), R39.2
/I2C Devices/LDCH06: R42.1, U12.26 (GPA5)
/I2C Devices/LDCH06A: D14.1 (K), R42.2
/I2C Devices/LDCH07: R43.1, U12.27 (GPA6)
/I2C Devices/LDCH07A: D15.1 (K), R43.2
/I2C Devices/LDCH08: R45.1, U12.28 (GPA7)
/I2C Devices/LDCH08A: D16.1 (K), R45.2
/I2C Devices/LDCH09: R46.1, U12.1 (GPB0)
/I2C Devices/LDCH09A: D17.1 (K), R46.2
/I2C Devices/LDCH10: R47.1, U12.2 (GPB1)
/I2C Devices/LDCH10A: D18.1 (K), R47.2
/I2C Devices/LDCH11: R48.1, U12.3 (GPB2)
/I2C Devices/LDCH11A: D19.1 (K), R48.2
/I2C Devices/LDCH12: R49.1, U12.4 (GPB3)
/I2C Devices/LDCH12A: D20.1 (K), R49.2
/I2C Devices/LDCH13: R50.1, U12.5 (GPB4)
/I2C Devices/LDCH13A: D21.1 (K), R50.2
/I2C Devices/LDCH14: R51.1, U12.6 (GPB5)
/I2C Devices/LDCH14A: D22.1 (K), R51.2
/I2C Devices/LDCH15: R52.1, U12.7 (GPB6)
/I2C Devices/LDCH15A: D23.1 (K), R52.2
/I2C Devices/LDCH16: R53.1, U12.8 (GPB7)
/I2C Devices/LDCH16A: D24.1 (K), R53.2
/I2C Devices/MCPOUTNRST: R44.2, U12.18 (~RESET)
GND: C30.2, C32.2, U10.4 (GND1), U12.10 (V_{SS}), U12.15 (A0), U12.16 (A1), U12.17 (A2); also elsewhere on the board
GNDA: C29.2, C31.2, U10.5 (GND2), U11.1 (A0), U11.2 (A1), U11.3 (A2), U11.4 (A3), U11.5 (A4), U11.14 (VSS), U11.23 (~OE), U11.24 (A5), U11.25 (EXTCLK); also elsewhere on the board

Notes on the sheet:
PWM ADDRESS 0x40
OUTPUTS ADDRESS 0x20
V_{F} = 1,8V @ 2,5mA I_{LED} = (3.3V - V_{F}) / R I_{LED} = (3.3V - 1.8V) / 680R I_{LED} = 2,20 mA
RESISTORS: 62,5mW WHERE NOT SPECIFIED
PCA9685 MUST BE CONFIGURED FOR PWM FREQUENCY OF 1526 Hz.

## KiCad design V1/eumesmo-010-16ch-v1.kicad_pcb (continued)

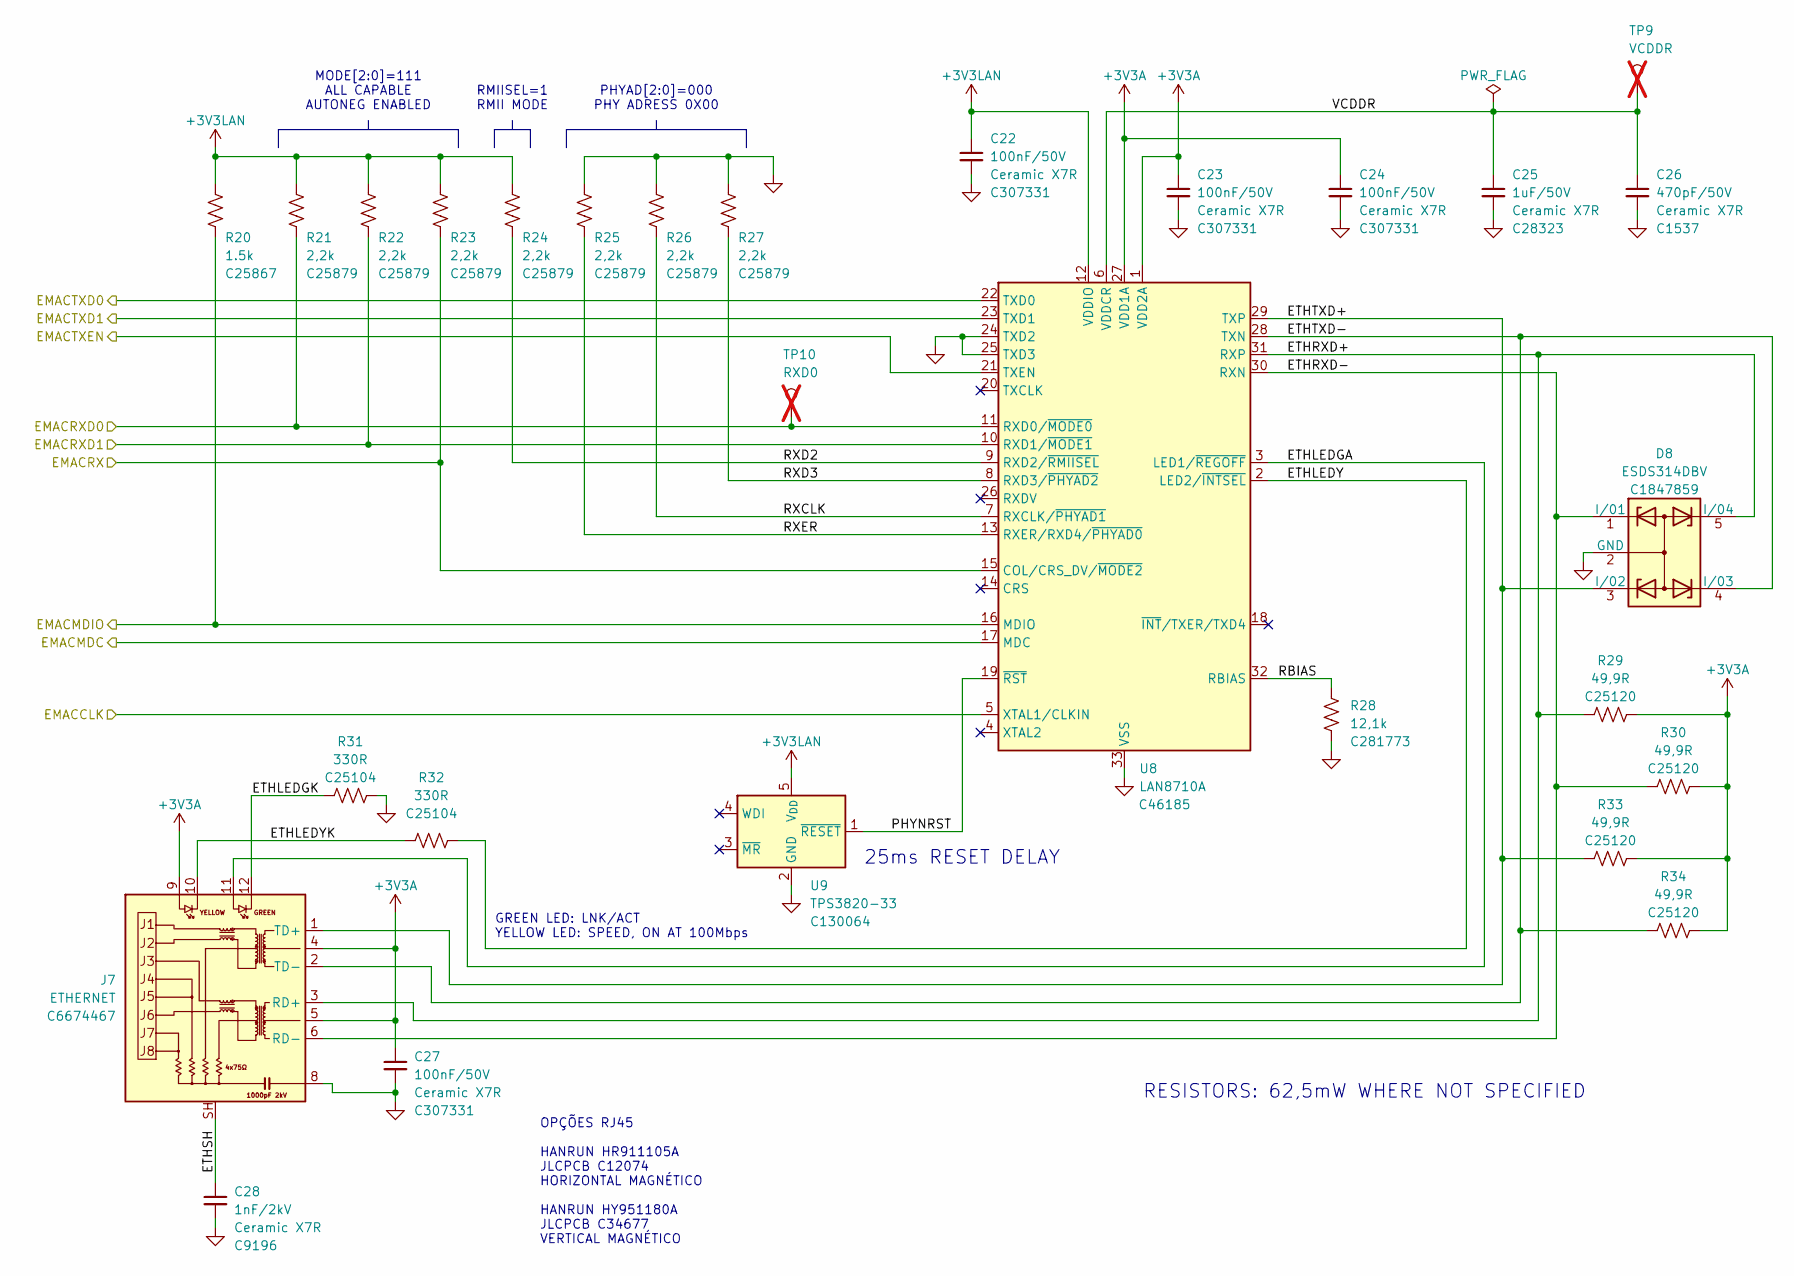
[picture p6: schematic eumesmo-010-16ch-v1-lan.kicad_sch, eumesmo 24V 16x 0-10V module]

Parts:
C22, C23, C24, C27: 100nF/50V; C_0402_1005Metric; Mfr PN CL05B104KB54PNC; LCSC Part # C307331
C25: 1uF/50V; C_0805_2012Metric; Mfr PN CL21B105KBFNNNE; LCSC Part # C28323
C26: 470pF/50V; C_0402_1005Metric; Mfr PN 0402B471K500NT; LCSC Part # C1537
C28: 1nF/2kV; C_1206_3216Metric; Mfr PN 1206B102K202NT; LCSC Part # C9196
D8: ESDS314DBV; SOT-23-5; Mfr PN ESDS314DBVR; LCSC Part # C1847859
J7: ETHERNET; RJ45_HanRun_HR915340A; Mfr PN HR915340AE; LCSC Part # C6674467
R20: 1.5k; R_0402_1005Metric; Mfr PN 0402WGF1501TCE; LCSC Part # C25867
R21, R22, R23, R24, R25, R26, R27: 2,2k; R_0402_1005Metric; Mfr PN 0402WGF2201TCE; LCSC Part # C25879
R28: 12,1k; R_0402_1005Metric; Mfr PN RT0402BRD0712K1L; LCSC Part # C281773
R29, R30, R33, R34: 49,9R; R_0402_1005Metric; Mfr PN 0402WGF499JTCE; LCSC Part # C25120
R31, R32: 330R; R_0402_1005Metric; Mfr PN 0402WGF3300TCE; LCSC Part # C25104
TP9: VCDDR; TestPoint_Pad_D1.5mm; not fitted
TP10: RXD0; TestPoint_Pad_D1.5mm; not fitted
U8: LAN8710A; QFN-32-1EP_5x5mm_P0.5mm_EP3.3x3.3mm_ThermalVias; Mfr PN LAN8710A-EZC-TR; LCSC Part # C46185
U9: TPS3820-33; SOT-23-5; Mfr PN TPS3820-33DBVR; LCSC Part # C130064

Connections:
+3V3A: C23.1, C24.1, C27.1, J7.4, J7.5, J7.9, R29.2, R30.2, R33.2, R34.2, U8.1 (VDD2A), U8.27 (VDD1A); also elsewhere on the board
+3V3LAN: C22.1, R20.1, R21.1, R22.1, R23.1, R24.1, U8.12 (VDDIO), U9.5 (V_{DD}); also elsewhere on the board
/LAN/EMACCLK: U8.5 (XTAL1/CLKIN); also elsewhere on the board
/LAN/EMACMDC: U8.17 (MDC); also elsewhere on the board
/LAN/EMACMDIO: R20.2, U8.16 (MDIO); also elsewhere on the board
/LAN/EMACRX: R23.2, U8.15 (COL/CRS_DV/~MODE2); also elsewhere on the board
/LAN/EMACRXD0: R21.2, TP10.1, U8.11 (RXD0/~MODE0); also elsewhere on the board
/LAN/EMACRXD1: R22.2, U8.10 (RXD1/~MODE1); also elsewhere on the board
/LAN/EMACTXD0: U8.22 (TXD0); also elsewhere on the board
/LAN/EMACTXD1: U8.23 (TXD1); also elsewhere on the board
/LAN/EMACTXEN: U8.21 (TXEN); also elsewhere on the board
/LAN/ETHLEDGA: J7.11, U8.3 (LED1/~REGOFF)
/LAN/ETHLEDGK: J7.12, R31.1
/LAN/ETHLEDY: R32.2, U8.2 (LED2/~INTSEL)
/LAN/ETHLEDYK: J7.10, R32.1
/LAN/ETHRXD+: D8.5 (I/04), J7.3 (RD+), R29.1, U8.31 (RXP)
/LAN/ETHRXD-: D8.1 (I/01), J7.6 (RD-), R30.1, U8.30 (RXN)
/LAN/ETHSH: C28.1, J7.SH
/LAN/ETHTXD+: D8.3 (I/02), J7.1 (TD+), R33.1, U8.29 (TXP)
/LAN/ETHTXD-: D8.4 (I/03), J7.2 (TD-), R34.1, U8.28 (TXN)
/LAN/PHYNRST: U8.19 (~RST), U9.1 (~RESET)
/LAN/RBIAS: R28.1, U8.32 (RBIAS)
/LAN/RXCLK: R26.2, U8.7 (RXCLK/~PHYAD1)
/LAN/RXD2: R24.2, U8.9 (RXD2/~RMIISEL)
/LAN/RXD3: R27.2, U8.8 (RXD3/~PHYAD2)
/LAN/RXER: R25.2, U8.13 (RXER/RXD4/~PHYAD0)
/LAN/VCDDR: C25.1, C26.1, U8.6 (VDDCR)
GND: C22.2, C23.2, C24.2, C25.2, C26.2, C27.2, C28.2, D8.2 (GND), J7.8, R25.1, R26.1, R27.1, R28.2, R31.2, U8.24 (TXD2), U8.25 (TXD3), U8.33 (VSS), U9.2 (GND); also elsewhere on the board

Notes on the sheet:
25ms RESET DELAY
OPÇÕES RJ45 HANRUN HR911105A JLCPCB C12074 HORIZONTAL MAGNÉTICO HANRUN HY951180A JLCPCB C34677 VERTICAL MAGNÉTICO
GREEN LED: LNK/ACT YELLOW LED: SPEED, ON AT 100Mbps
MODE[2:0]=111 ALL CAPABLE AUTONEG ENABLED
PHYAD[2:0]=000 PHY ADRESS 0X00
RMIISEL=1 RMII MODE
RESISTORS: 62,5mW WHERE NOT SPECIFIED

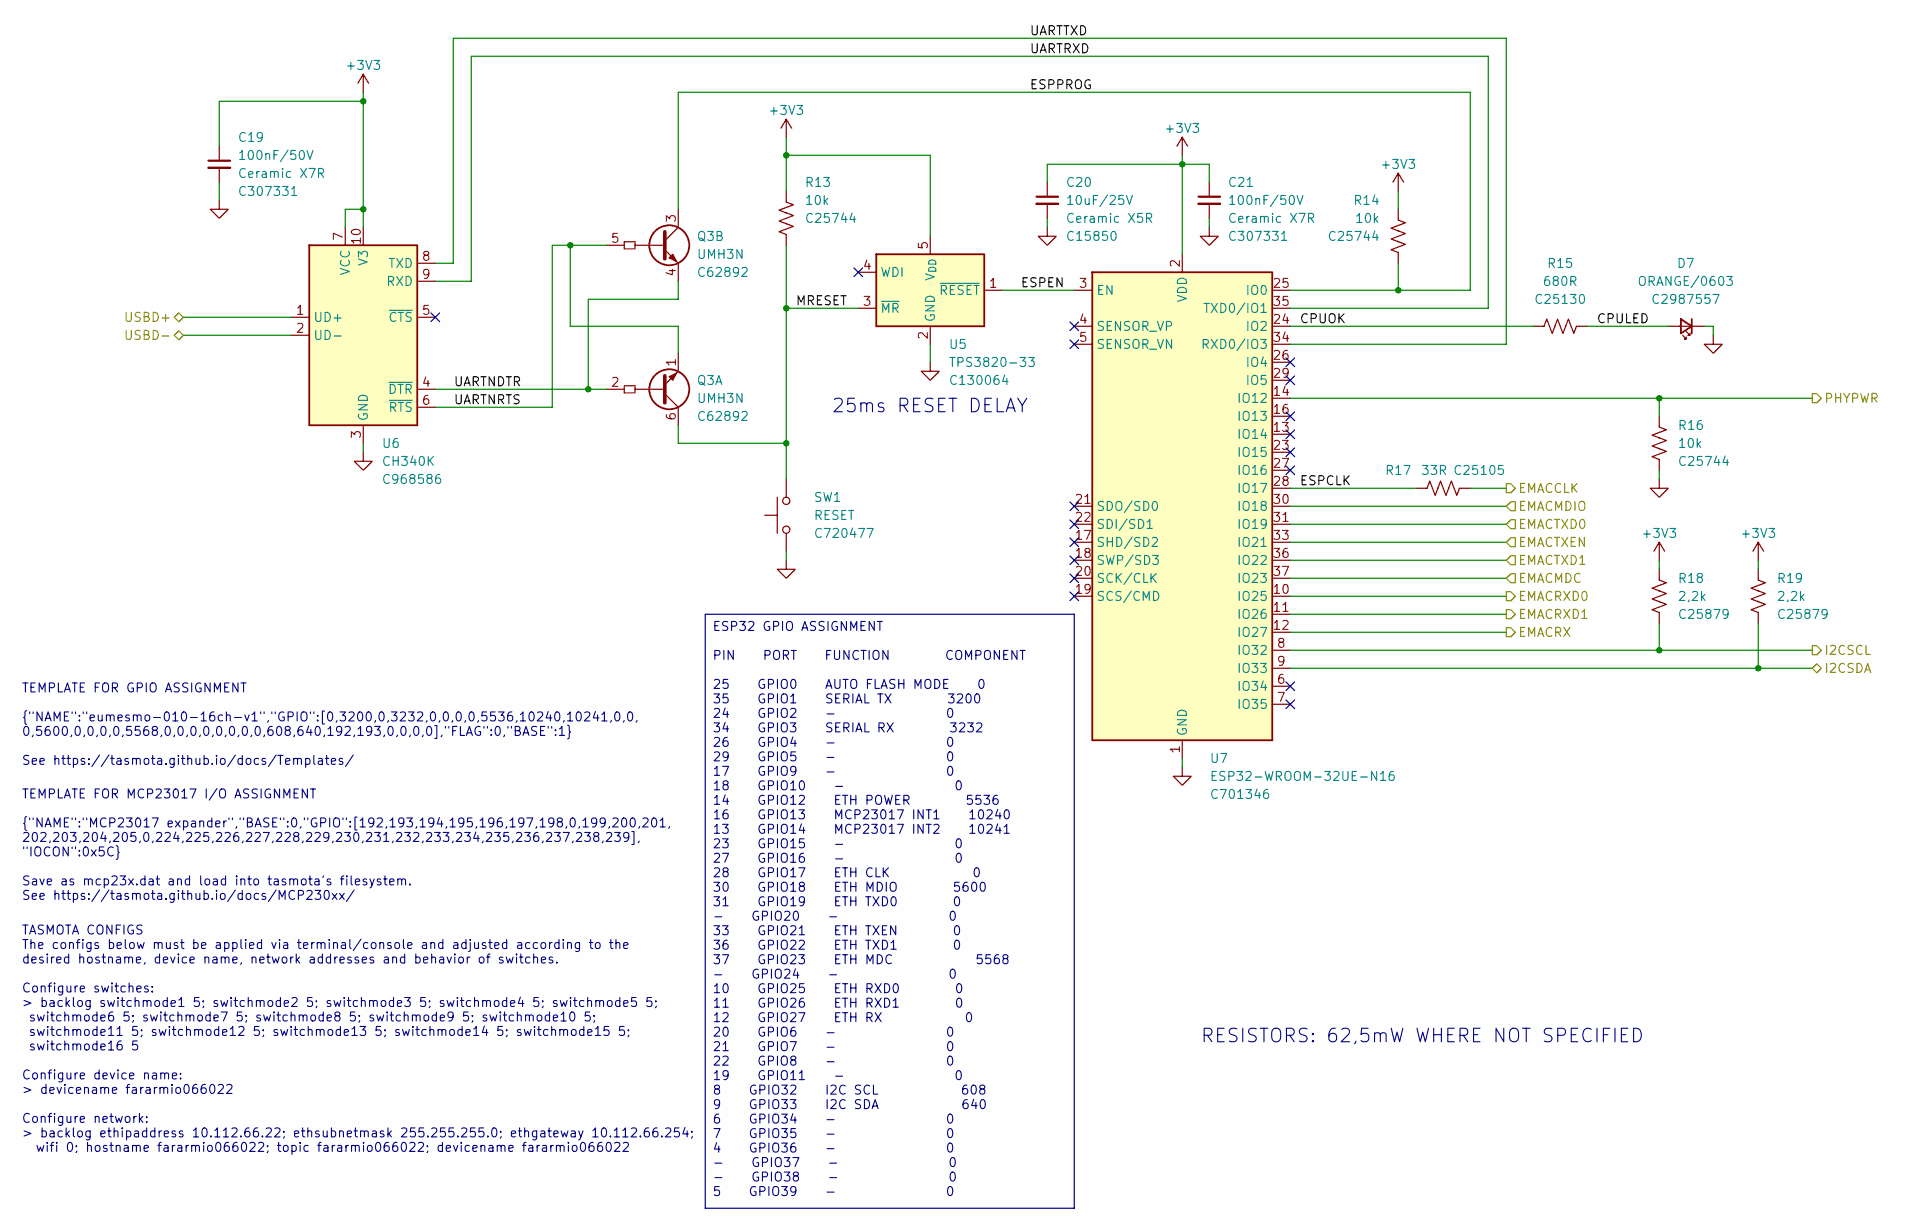
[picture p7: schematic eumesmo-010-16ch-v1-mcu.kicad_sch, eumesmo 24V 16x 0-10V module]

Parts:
C19, C21: 100nF/50V; C_0402_1005Metric; Mfr PN CL05B104KB54PNC; LCSC Part # C307331
C20: 10uF/25V; C_0805_2012Metric; Mfr PN CL21A106KAYNNNE; LCSC Part # C15850
D7: ORANGE/0603; LED_0603_1608Metric; Mfr PN 19-217/S2C-AL1M2VY/6T; LCSC Part # C2987557
Q3: UMH3N; SOT-363_SC-70-6; Mfr PN UMH3N; LCSC Part # C62892
R13, R14, R16: 10k; R_0402_1005Metric; Mfr PN 0402WGF1002TCE; LCSC Part # C25744
R15: 680R; R_0402_1005Metric; Mfr PN 0402WGF6800TCE; LCSC Part # C25130
R17: 33R; R_0402_1005Metric; Mfr PN 0402WGF330JTCE; LCSC Part # C25105
R18, R19: 2,2k; R_0402_1005Metric; Mfr PN 0402WGF2201TCE; LCSC Part # C25879
SW1: RESET; SW_SPST_Xunpu_TS1088AR02016; Mfr PN TS-1088-AR02016; LCSC Part # C720477
U5: TPS3820-33; SOT-23-5; Mfr PN TPS3820-33DBVR; LCSC Part # C130064
U6: CH340K; SSOP-10-1EP_3.9x4.9mm_P1mm_EP2.1x3.3mm; Mfr PN CH340K; LCSC Part # C968586
U7: ESP32-WROOM-32UE-N16; ESP32-WROOM-32U; Mfr PN ESP32-WROOM-32UE-N16; LCSC Part # C701346

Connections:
+3V3: C19.1, C20.1, C21.1, R13.1, R14.1, R18.1, R19.1, U5.5 (V_{DD}), U6.7 (VCC), U6.10 (V3), U7.2 (VDD); also elsewhere on the board
/I2C Devices/I2CSCL: R18.2, U7.8 (IO32); also elsewhere on the board
/I2C Devices/I2CSDA: R19.2, U7.9 (IO33); also elsewhere on the board
/LAN/EMACCLK: R17.2; also elsewhere on the board
/LAN/EMACMDC: U7.37 (IO23); also elsewhere on the board
/LAN/EMACMDIO: U7.30 (IO18); also elsewhere on the board
/LAN/EMACRX: U7.12 (IO27); also elsewhere on the board
/LAN/EMACRXD0: U7.10 (IO25); also elsewhere on the board
/LAN/EMACRXD1: U7.11 (IO26); also elsewhere on the board
/LAN/EMACTXD0: U7.31 (IO19); also elsewhere on the board
/LAN/EMACTXD1: U7.36 (IO22); also elsewhere on the board
/LAN/EMACTXEN: U7.33 (IO21); also elsewhere on the board
/MCU/CPULED: D7.2 (A), R15.2
/MCU/CPUOK: R15.1, U7.24 (IO2)
/MCU/ESPCLK: R17.1, U7.28 (IO17)
/MCU/ESPEN: U5.1 (~RESET), U7.3 (EN)
/MCU/ESPPROG: Q3.3 (C2), R14.2, U7.25 (IO0)
/MCU/MRESET: Q3.6 (C1), R13.2, SW1.2, U5.3 (~MR)
/MCU/PHYPWR: R16.1, U7.14 (IO12); also elsewhere on the board
/MCU/UARTNDTR: Q3.2 (B1), Q3.4 (E2), U6.4 (~DTR)
/MCU/UARTNRTS: Q3.1 (E1), Q3.5 (B2), U6.6 (~RTS)
/MCU/UARTRXD: U6.9 (RXD), U7.35 (TXD0/IO1)
/MCU/UARTTXD: U6.8 (TXD), U7.34 (RXD0/IO3)
/MCU/USBD+: U6.1 (UD+); also elsewhere on the board
/MCU/USBD-: U6.2 (UD-); also elsewhere on the board
GND: C19.2, C20.2, C21.2, D7.1 (K), R16.2, SW1.1, U5.2 (GND), U6.3 (GND), U6.11 (GND), U7.1 (GND), U7.15 (GND), U7.38 (GND), U7.39 (GND); also elsewhere on the board

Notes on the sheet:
TASMOTA CONFIGS The configs below must be applied via terminal/console and adjusted according to the desired hostname, device name, network addresses and behavior of switches. Configure switches: > backlog switchmode1 5; switchmode2 5; switchmode3 5; switchmode4 5; switchmode5 5; switchmode6 5; swi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
25ms RESET DELAY
TEMPLATE FOR GPIO ASSIGNMENT {"NAME":"eumesmo-010-16ch-v1","GPIO":[0,3200,0,3232,0,0,0,0,5536,10240,10241,0,0, 0,5600,0,0,0,0,5568,0,0,0,0,0,0,0,0,608,640,192,193,0,0,0,0],"FLAG":0,"BASE":1} See https://tasmota.github.io/docs/Templates/
TEMPLATE FOR MCP23017 I/O ASSIGNMENT {"NAME":"MCP23017 expander","BASE":0,"GPIO":[192,193,194,195,196,197,198,0,199,200,201, 202,203,204,205,0,224,225,226,227,228,229,230,231,232,233,234,235,236,237,238,239], "IOCON":0x5C} Save as mcp23x.dat and load into tasmota's filesystem. See https://tasmota.g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
RESISTORS: 62,5mW WHERE NOT SPECIFIED
ESP32 GPIO ASSIGNMENT PIN PORT FUNCTION COMPONENT 25 GPIO0 AUTO FLASH MODE 0 35 GPIO1 SERIAL TX 3200 24 GPIO2 - 0 34 GPIO3 SERIAL RX 3232 26 GPIO4 - 0 29 GPIO5 - 0 17 GPIO9 - 0 18 GPIO10 - 0 14 GPIO12 ETH POWER 5536 16 GPIO13 MCP23017 INT1 10240 13 GPIO14 MCP23017 INT2 10241 23 GPIO15 - 0 27 GPIO16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

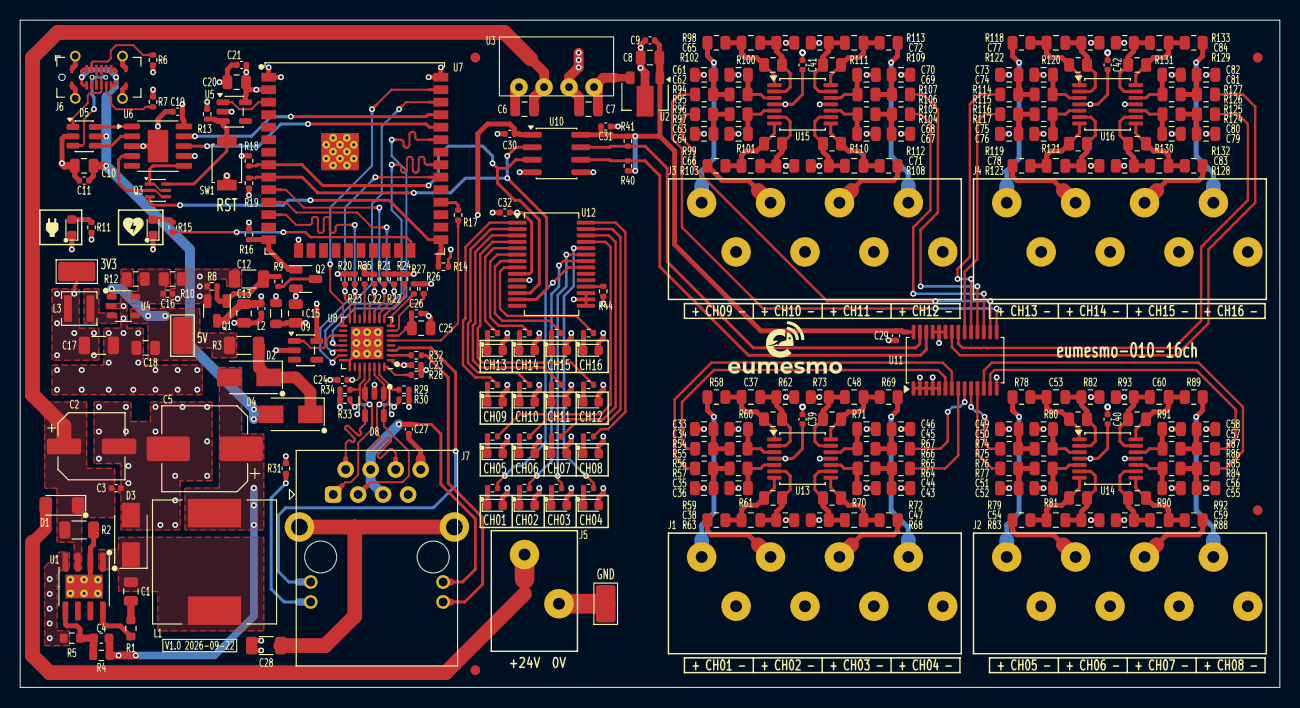
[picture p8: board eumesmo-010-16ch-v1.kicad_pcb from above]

Board: 4 copper layers, 128.0 x 67.8 mm, 278 parts (0 on the bottom side), 198 nets.

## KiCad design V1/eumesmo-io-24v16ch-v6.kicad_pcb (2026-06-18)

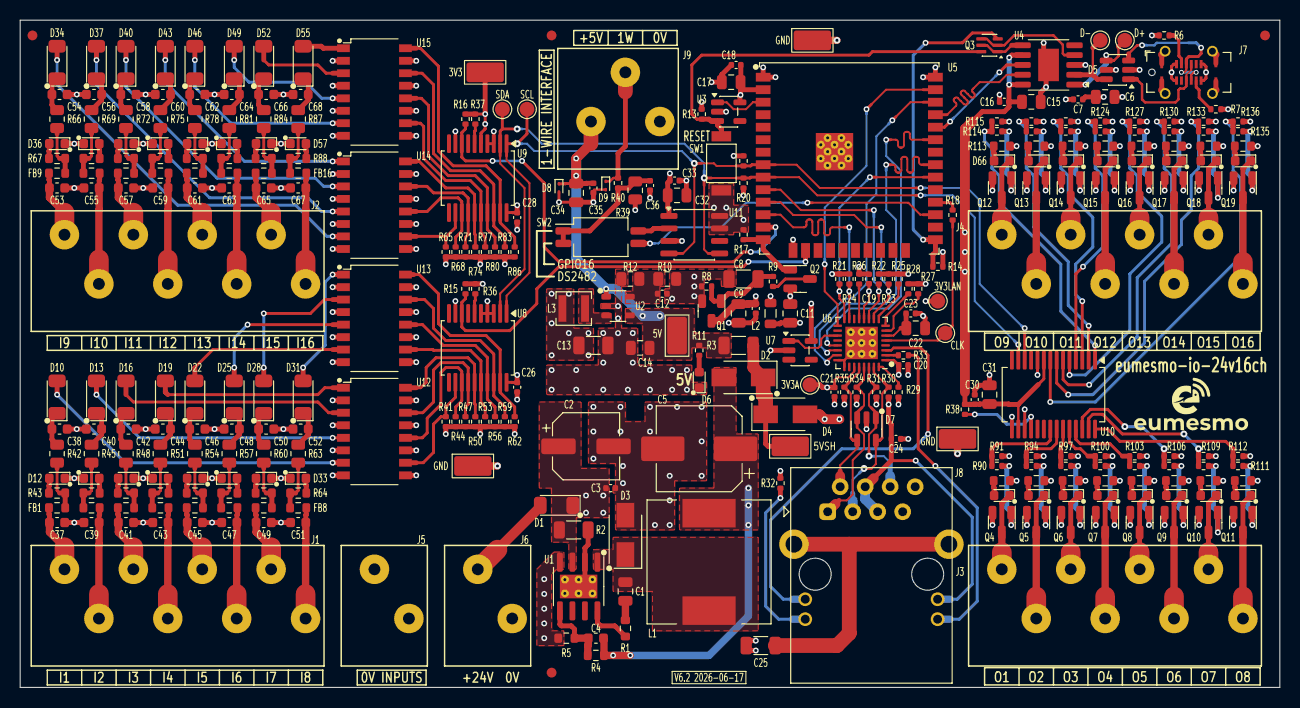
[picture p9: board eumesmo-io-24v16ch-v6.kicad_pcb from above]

Board: 4 copper layers, 128.0 x 67.8 mm, 340 parts (0 on the bottom side), 232 nets.

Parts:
C1: 100nF/100V; C_0805_2012Metric
C2: 47uF/35V; CP_Elec_6.3x5.4
C3, C7, C10, C16, C18, C19, C20, C21, C24, C26, C28, C30, C33, C35: 100nF/50V; C_0402_1005Metric
C4: 12pF/50V; C_0603_1608Metric
C5: 470uF/16V; CP_Elec_8x10.5
C6, C22: 1uF/50V; C_0805_2012Metric
C8, C13: 22uF/10V; C_1206_3216Metric
C9, C11, C14, C15, C17, C31, C32, C34: 10uF/25V; C_0805_2012Metric
C12: 22pF/50V; C_0402_1005Metric
C23, C36: 470pF/50V; C_0402_1005Metric
C25: 1nF/2kV; C_1206_3216Metric
C37, C39, C41, C43, C45, C47, C49, C51, C53, C55, C57, C59, C61, C63, C65, C67: 1nF/50V; C_0603_1608Metric
C38, C40, C42, C44, C46, C48, C50, C52, C54, C56, C58, C60, C62, C64, C66, C68: 33nF/50V; C_0603_1608Metric
D1: SM4007PL; D_SOD-123
D2, D4: SS34; D_SMA
D3: SS510; D_SMA
D5: USBLC6-2SC6; SOT-23-6
D6, D12, D15, D18, D21, D24, D27, D30, D33, D36, D39, D42, D45, D48, D51, D54, D57, D58, D59, D60, D61, D62, D63, D64, D65, D66, D67, D68, D69, D70, D71, D72, D73: WHITE/0603; LED_0603_1608Metric
D7: ESDS314DBV; SOT-23-5
D8, D9: ESD9L5.0; D_SOD-923
D10, D13, D16, D19, D22, D25, D28, D31, D34, D37, D40, D43, D46, D49, D52, D55: 9V1/500mW; D_SOD-123
FB1, FB2, FB3, FB4, FB5, FB6, FB7, FB8, FB9, FB10, FB11, FB12, FB13, FB14, FB15, FB16: 600R/100MHz; R_0603_1608Metric
FID1, FID2, FID3, FID4: Fiducial; Fiducial_1mm_Mask2mm
J1, J2, J3, J4: 250-208; TerminalBlock_Wago_250-208_1x08_P3.5mm_45Degree
J5, J6: 250-202; TerminalBlock_Wago_250-202_1x02_P3.5mm_45Degree
J7: USB_C_Receptacle_USB2.0; USB_C_Receptacle_ShouHan_TYPE-C-16PLT-H10.0
J8: ETHERNET; RJ45_HanRun_HR915340A
J9: 250-203; TerminalBlock_Wago_250-203_1x03_P3.5mm_45Degree
L1: 33uH 2,1A; L_12x12mm_H6mm
L2: 2A 600R; L_0805_2012Metric
L3: 2,2uH 1,5A; L_3x3mm_H1.5mm
Q1: WPM2015-3/TR; SOT-23
Q2: MMUN2211LT3G; SOT-23
Q3: UMH3N; SOT-363_SC-70-6
Q4, Q5, Q6, Q7, Q8, Q9, Q10, Q11, Q12, Q13, Q14, Q15, Q16, Q17, Q18, Q19: MMBT2222A; SOT-23-Narrow
R1: 5,1R/100mW; R_0603_1608Metric
R2: 30mR/333mW; R_1206_3216Metric
R3: 0,1R; C_1206_3216Metric
R4: 300k/100mW; R_0603_1608Metric
R5: 52,3k/100mW; R_0603_1608Metric
R6, R7: 5,1k; R_0402_1005Metric
R8, R13, R14, R17, R91, R94, R97, R100, R103, R106, R109, R112, R115, R118, R121, R124, R127, R130, R133, R136: 10k; R_0402_1005Metric
R9, R11, R36, R37, R38: 1k; R_0402_1005Metric
R10: 100k/125mW; R_0805_2012Metric
R12: 22,1k/125mW; R_0805_2012Metric
R15, R16, R19, R20, R41, R44, R47, R50, R53, R56, R59, R62, R65, R68, R71, R74, R77, R80, R83, R86: 2k2; R_0402_1005Metric
R18, R40: 33R; R_0402_1005Metric
R21: 1.5k; R_0402_1005Metric
R22, R23, R24, R25, R26, R27, R28: 2.2k; R_0402_1005Metric
R29: 12,1k; R_0402_1005Metric
R30, R31, R34, R35: 49,9R; R_0402_1005Metric
R32, R33: 330R; R_0402_1005Metric
R39, R42, R45, R48, R51, R54, R57, R60, R63, R66, R69, R72, R75, R78, R81, R84, R87: 1k8/125mW; R_0805_2012Metric
R43, R46, R49, R52, R55, R58, R61, R64, R67, R70, R73, R76, R79, R82, R85, R88, R89, R92, R95, R98, R101, R104, R107, R110, R113, R116, R119, R122, R125, R128, R131, R134: 10k/100mW; R_0603_1608Metric
R90, R93, R96, R99, R102, R105, R108, R111, R114, R117, R120, R123, R126, R129, R132, R135: 470R; R_0402_1005Metric
SW1: RESET; SW_SPST_Xunpu_TS1088AR02016
SW2: 1WIRE_SEL; SW_DIP_SPSTx02_Slide_Copal_CHS-02B_W7.62mm_P1.27mm
TP1: 5VSH; TestPoint_Keystone_5019_Miniature
TP2: 5V; TestPoint_Keystone_5019_Miniature
TP3, TP4, TP5: GND; TestPoint_Keystone_5019_Miniature
TP6: 3V3A; TestPoint_Pad_D1.5mm
TP7: 3V3LAN; TestPoint_Pad_D1.5mm
TP9: 3V3; TestPoint_Keystone_5019_Miniature
TP11: D+; TestPoint_Pad_D1.5mm
TP12: D-; TestPoint_Pad_D1.5mm
TP15: CLK; TestPoint_Pad_D1.5mm
TP16: SDA; TestPoint_Pad_D1.5mm
TP17: SCL; TestPoint_Pad_D1.5mm
U1: TX4138; SOIC-8-1EP_3.9x4.9mm_P1.27mm_EP2.41x3.81mm_ThermalVias
U2: SY8089A1AAC; SOT-23-5_Shorter_Pins
U3: TPS3820-33; SOT-23-5
U4: CH340K; SSOP-10-1EP_3.9x4.9mm_P1mm_EP2.1x3.3mm
U5: ESP32-WROOM-32UE-N16; ESP32-WROOM-32U
U6: LAN8710A; QFN-32-1EP_5x5mm_P0.5mm_EP3.3x3.3mm_ThermalVias
U7: TPS3823-33; SOT-23-5
U8, U9: MCP23008; SSOP-20_5.3x7.2mm_P0.65mm
U10: MCP23017; SSOP-28_5.3x10.2mm_P0.65mm
U11: DS2482S-100; SO-8_3.9x4.9mm_P1.27mm
U12, U13, U14, U15: OR-3H7-4; SOP-16_4.4x10.4mm_P1.27mm

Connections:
+3V3: C8.1, C12.1, C13.1, C15.1, C16.1, C17.1, C18.1, C26.1, C28.1, C30.1, C31.1, C32.1, C33.1, L3.2, Q1.2 (S), R8.1, R10.1, R13.1, R14.1, R15.1, R16.1, R19.1, R20.1, R36.1, R37.1, R38.1, R39.1, R41.1, R44.1, R47.1, R50.1, R53.1, R56.1, R59.1, R62.1, R65.1, R68.1, R71.1, R74.1, R77.1, R80.1, R83.1, R86.1, TP9.1 (1_1), U3.5 (V_{DD}), U4.7 (VCC), U4.10 (V3), U5.2 (VDD), U8.20 (VDD), U9.5 (A0), U9.20 (VDD), U10.9 (V_{DD}), U10.16 (A1), U11.1 (V_{CC})
+3V3A: C11.1, C20.1, C21.1, C24.1, J8.4, J8.5, J8.9, L2.2, R30.2, R31.2, R34.2, R35.2, TP6.1 (1_1), U6.1 (VDD2A), U6.27 (VDD1A)
+3V3LAN: C9.1, C10.1, C19.1, L2.1, Q1.3 (D), R21.1, R22.1, R23.1, R24.1, R25.1, TP7.1 (1_1), U6.12 (VDDIO), U7.5 (V_{DD})
+5V: C14.1, C34.1, C35.1, D8.1 (K), J9.1, R3.1, R11.1, TP2.1 (1_1), U2.1 (EN), U2.4 (IN)
+24V: C2.1, C3.1, D1.1 (K), R2.1, R89.1, R92.1, R95.1, R98.1, R101.1, R104.1, R107.1, R110.1, R113.1, R116.1, R119.1, R122.1, R125.1, R128.1, R131.1, R134.1, U1.3 (VIN)
/I2C Devices/1WIREBUS: C36.1, R39.2, R40.2, SW2.1, SW2.2
/I2C Devices/1WIREFIELD: D9.1 (K), J9.2, R40.1
/I2C Devices/1WIREGPIO: SW2.3, U5.27 (IO16)
/I2C Devices/1WIREMASTER: SW2.4, U11.2 (IO)
/I2C Devices/I2CSCL: R19.2, TP17.1 (1_1), U5.8 (IO32), U8.1 (SCL), U9.1 (SCL), U10.12 (SCK), U11.4 (SCL)
/I2C Devices/I2CSDA: R20.2, TP16.1 (1_1), U5.9 (IO33), U8.2 (SDA), U9.2 (SDA), U10.13 (SDA), U11.5 (SDA)
/I2C Devices/MCPIN1INT: R15.2, U5.16 (IO13), U8.8 (INT)
/I2C Devices/MCPIN2INT: R16.2, U5.13 (IO14), U9.8 (INT)
/I2C Devices/MCPINN1RST: R36.2, U8.6 (~RESET)
/I2C Devices/MCPINN2RST: R37.2, U9.6 (~RESET)
/I2C Devices/MCPOUTNRST: R38.2, U10.18 (~RESET)
/IN1: C37.1, FB1.1, J1.1
/IN2: C39.1, FB2.1, J1.2
/IN3: C41.1, FB3.1, J1.3
/IN4: C43.1, FB4.1, J1.4
/IN5: C45.1, FB5.1, J1.5
/IN6: C47.1, FB6.1, J1.6
/IN7: C49.1, FB7.1, J1.7
/IN8: C51.1, FB8.1, J1.8
/IN9: C53.1, FB9.1, J2.1
/IN10: C55.1, FB10.1, J2.2
/IN11: C57.1, FB11.1, J2.3
/IN12: C59.1, FB12.1, J2.4
/IN13: C61.1, FB13.1, J2.5
/IN14: C63.1, FB14.1, J2.6
/IN15: C65.1, FB15.1, J2.7
/IN16: C67.1, FB16.1, J2.8
/INPUT1: R41.2, U8.12 (GP0), U12.10
/INPUT2: R44.2, U8.13 (GP1), U12.12
/INPUT3: R47.2, U8.14 (GP2), U12.14
/INPUT4: R50.2, U8.15 (GP3), U12.16
/INPUT5: R53.2, U8.16 (GP4), U13.10
/INPUT6: R56.2, U8.17 (GP5), U13.12
/INPUT7: R59.2, U8.18 (GP6), U13.14
/INPUT8: R62.2, U8.19 (GP7), U13.16
/INPUT9: R65.2, U9.12 (GP0), U14.10
/INPUT10: R68.2, U9.13 (GP1), U14.12
/INPUT11: R71.2, U9.14 (GP2), U14.14
/INPUT12: R74.2, U9.15 (GP3), U14.16
/INPUT13: R77.2, U9.16 (GP4), U15.10
/INPUT14: R80.2, U9.17 (GP5), U15.12
/INPUT15: R83.2, U9.18 (GP6), U15.14
/INPUT16: R86.2, U9.19 (GP7), U15.16
/Input 1/INFILTER: C38.1, D10.1 (K), R42.1
/Input 1/INLED: D12.2 (A), R43.2
/Input 1/INOPTO: D10.2 (A), U12.7
/Input 1/INPRE: FB1.2, R42.2, R43.1
/Input 2/INFILTER: C40.1, D13.1 (K), R45.1
/Input 2/INLED: D15.2 (A), R46.2
/Input 2/INOPTO: D13.2 (A), U12.5
/Input 2/INPRE: FB2.2, R45.2, R46.1
/Input 3/INFILTER: C42.1, D16.1 (K), R48.1
/Input 3/INLED: D18.2 (A), R49.2
/Input 3/INOPTO: D16.2 (A), U12.3
/Input 3/INPRE: FB3.2, R48.2, R49.1
/Input 4/INFILTER: C44.1, D19.1 (K), R51.1
/Input 4/INLED: D21.2 (A), R52.2
/Input 4/INOPTO: D19.2 (A), U12.1
/Input 4/INPRE: FB4.2, R51.2, R52.1
/Input 5/INFILTER: C46.1, D22.1 (K), R54.1
/Input 5/INLED: D24.2 (A), R55.2
/Input 5/INOPTO: D22.2 (A), U13.7
/Input 5/INPRE: FB5.2, R54.2, R55.1
/Input 6/INFILTER: C48.1, D25.1 (K), R57.1
/Input 6/INLED: D27.2 (A), R58.2
/Input 6/INOPTO: D25.2 (A), U13.5
/Input 6/INPRE: FB6.2, R57.2, R58.1
/Input 7/INFILTER: C50.1, D28.1 (K), R60.1
/Input 7/INLED: D30.2 (A), R61.2
/Input 7/INOPTO: D28.2 (A), U13.3
/Input 7/INPRE: FB7.2, R60.2, R61.1
/Input 8/INFILTER: C52.1, D31.1 (K), R63.1
/Input 8/INLED: D33.2 (A), R64.2
/Input 8/INOPTO: D31.2 (A), U13.1
/Input 8/INPRE: FB8.2, R63.2, R64.1
/Input 9/INFILTER: C54.1, D34.1 (K), R66.1
/Input 9/INLED: D36.2 (A), R67.2
/Input 9/INOPTO: D34.2 (A), U14.7
/Input 9/INPRE: FB9.2, R66.2, R67.1
/Input 10/INFILTER: C56.1, D37.1 (K), R69.1
/Input 10/INLED: D39.2 (A), R70.2
/Input 10/INOPTO: D37.2 (A), U14.5
/Input 10/INPRE: FB10.2, R69.2, R70.1
/Input 11/INFILTER: C58.1, D40.1 (K), R72.1
/Input 11/INLED: D42.2 (A), R73.2
/Input 11/INOPTO: D40.2 (A), U14.3
/Input 11/INPRE: FB11.2, R72.2, R73.1
/Input 12/INFILTER: C60.1, D43.1 (K), R75.1
/Input 12/INLED: D45.2 (A), R76.2
/Input 12/INOPTO: D43.2 (A), U14.1
/Input 12/INPRE: FB12.2, R75.2, R76.1
/Input 13/INFILTER: C62.1, D46.1 (K), R78.1
/Input 13/INLED: D48.2 (A), R79.2
/Input 13/INOPTO: D46.2 (A), U15.7
/Input 13/INPRE: FB13.2, R78.2, R79.1
/Input 14/INFILTER: C64.1, D49.1 (K), R81.1
/Input 14/INLED: D51.2 (A), R82.2
/Input 14/INOPTO: D49.2 (A), U15.5
/Input 14/INPRE: FB14.2, R81.2, R82.1
/Input 15/INFILTER: C66.1, D52.1 (K), R84.1
/Input 15/INLED: D54.2 (A), R85.2
/Input 15/INOPTO: D52.2 (A), U15.3
/Input 15/INPRE: FB15.2, R84.2, R85.1
/Input 16/INFILTER: C68.1, D55.1 (K), R87.1
/Input 16/INLED: D57.2 (A), R88.2
/Input 16/INOPTO: D55.2 (A), U15.1
/Input 16/INPRE: FB16.2, R87.2, R88.1
/LAN/EMACCLK: R18.2, TP15.1 (1_1), U6.5 (XTAL1/CLKIN)
/LAN/EMACMDC: U5.37 (IO23), U6.17 (MDC)
/LAN/EMACMDIO: R21.2, U5.30 (IO18), U6.16 (MDIO)
/LAN/EMACRX: R24.2, U5.12 (IO27), U6.15 (COL/CRS_DV/~MODE2)
/LAN/EMACRXD0: R22.2, U5.10 (IO25), U6.11 (RXD0/~MODE0)
/LAN/EMACRXD1: R23.2, U5.11 (IO26), U6.10 (RXD1/~MODE1)
/LAN/EMACTXD0: U5.31 (IO19), U6.22 (TXD0)
/LAN/EMACTXD1: U5.36 (IO22), U6.23 (TXD1)
/LAN/EMACTXEN: U5.33 (IO21), U6.21 (TXEN)
/LAN/ETHLEDGA: J8.11, U6.3 (LED1/~REGOFF)
/LAN/ETHLEDGK: J8.12, R32.1
/LAN/ETHLEDY: R33.2, U6.2 (LED2/~INTSEL)
/LAN/ETHLEDYK: J8.10, R33.1
/LAN/ETHRXD+: D7.5 (I/04), J8.3 (RD+), R30.1, U6.31 (RXP)
/LAN/ETHRXD-: D7.1 (I/01), J8.6 (RD-), R31.1, U6.30 (RXN)
/LAN/ETHSH: C25.1, J8.SH
/LAN/ETHTXD+: D7.3 (I/02), J8.1 (TD+), R34.1, U6.29 (TXP)
/LAN/ETHTXD-: D7.4 (I/03), J8.2 (TD-), R35.1, U6.28 (TXN)
/LAN/PHYNRST: U6.19 (~RST), U7.1 (~RESET)
/LAN/RBIAS: R29.1, U6.32 (RBIAS)
/LAN/RXCLK: R27.2, U6.7 (RXCLK/~PHYAD1)
/LAN/RXD2: R25.2, U6.9 (RXD2/~RMIISEL)
/LAN/RXD3: R28.2, U6.8 (RXD3/~PHYAD2)
/LAN/RXER: R26.2, U6.13 (RXER/RXD4/~PHYAD0)
/LAN/VCDDR: C22.1, C23.1, U6.6 (VDDCR)
/MCU/ESPCLK: R18.1, U5.28 (IO17)
/MCU/ESPEN: U3.1 (~RESET), U5.3 (EN)
/MCU/ESPPROG: Q3.3 (C2), R14.2, U5.25 (IO0)
/MCU/MRESET: Q3.6 (C1), R13.2, SW1.2, U3.3 (~MR)
/MCU/PHYPWR: Q2.1 (B), R17.1, U5.14 (IO12)
/MCU/UARTNDTR: Q3.2 (B1), Q3.4 (E2), U4.4 (~DTR)
/MCU/UARTNRTS: Q3.1 (E1), Q3.5 (B2), U4.6 (~RTS)
/MCU/UARTRXD: U4.9 (RXD), U5.35 (TXD0/IO1)
/MCU/UARTTXD: U4.8 (TXD), U5.34 (RXD0/IO3)
/MCU/USBD+: D5.4 (I/O2), TP11.1 (1_1), U4.1 (UD+)
/MCU/USBD-: D5.6 (I/O1), TP12.1 (1_1), U4.2 (UD-)
/OUT1: D58.1 (K), J3.1, Q4.3 (C)
/OUT2: D59.1 (K), J3.2, Q5.3 (C)
/OUT3: D60.1 (K), J3.3, Q6.3 (C)
/OUT4: D61.1 (K), J3.4, Q7.3 (C)
/OUT5: D62.1 (K), J3.5, Q8.3 (C)
/OUT6: D63.1 (K), J3.6, Q9.3 (C)
/OUT7: D64.1 (K), J3.7, Q10.3 (C)
/OUT8: D65.1 (K), J3.8, Q11.3 (C)
/OUT9: D66.1 (K), J4.1, Q12.3 (C)
/OUT10: D67.1 (K), J4.2, Q13.3 (C)
/OUT11: D68.1 (K), J4.3, Q14.3 (C)
/OUT12: D69.1 (K), J4.4, Q15.3 (C)
/OUT13: D70.1 (K), J4.5, Q16.3 (C)
/OUT14: D71.1 (K), J4.6, Q17.3 (C)
/OUT15: D72.1 (K), J4.7, Q18.3 (C)
/OUT16: D73.1 (K), J4.8, Q19.3 (C)
/OUTPUT1: R90.2, R91.2, U10.21 (GPA0)
/OUTPUT2: R93.2, R94.2, U10.22 (GPA1)
/OUTPUT3: R96.2, R97.2, U10.23 (GPA2)
/OUTPUT4: R99.2, R100.2, U10.24 (GPA3)
/OUTPUT5: R102.2, R103.2, U10.25 (GPA4)
/OUTPUT6: R105.2, R106.2, U10.26 (GPA5)
/OUTPUT7: R108.2, R109.2, U10.27 (GPA6)
/OUTPUT8: R111.2, R112.2, U10.28 (GPA7)
/OUTPUT9: R114.2, R115.2, U10.1 (GPB0)
/OUTPUT10: R117.2, R118.2, U10.2 (GPB1)
/OUTPUT11: R120.2, R121.2, U10.3 (GPB2)
/OUTPUT12: R123.2, R124.2, U10.4 (GPB3)
/OUTPUT13: R126.2, R127.2, U10.5 (GPB4)
/OUTPUT14: R129.2, R130.2, U10.6 (GPB5)
/OUTPUT15: R132.2, R133.2, U10.7 (GPB6)
/OUTPUT16: R135.2, R136.2, U10.8 (GPB7)
/Output 1/OUTBASE: Q4.1 (B), R90.1
/Output 1/OUTLED: D58.2 (A), R89.2
/Output 2/OUTBASE: Q5.1 (B), R93.1
/Output 2/OUTLED: D59.2 (A), R92.2
/Output 3/OUTBASE: Q6.1 (B), R96.1
/Output 3/OUTLED: D60.2 (A), R95.2
/Output 4/OUTBASE: Q7.1 (B), R99.1
/Output 4/OUTLED: D61.2 (A), R98.2
/Output 5/OUTBASE: Q8.1 (B), R102.1
/Output 5/OUTLED: D62.2 (A), R101.2
/Output 6/OUTBASE: Q9.1 (B), R105.1
/Output 6/OUTLED: D63.2 (A), R104.2
/Output 7/OUTBASE: Q10.1 (B), R108.1
/Output 7/OUTLED: D64.2 (A), R107.2
/Output 8/OUTBASE: Q11.1 (B), R111.1
/Output 8/OUTLED: D65.2 (A), R110.2
/Output 9/OUTBASE: Q12.1 (B), R114.1
/Output 9/OUTLED: D66.2 (A), R113.2
/Output 10/OUTBASE: Q13.1 (B), R117.1
/Output 10/OUTLED: D67.2 (A), R116.2
/Output 11/OUTBASE: Q14.1 (B), R120.1
/Output 11/OUTLED: D68.2 (A), R119.2
/Output 12/OUTBASE: Q15.1 (B), R123.1
/Output 12/OUTLED: D69.2 (A), R122.2
/Output 13/OUTBASE: Q16.1 (B), R126.1
/Output 13/OUTLED: D70.2 (A), R125.2
/Output 14/OUTBASE: Q17.1 (B), R129.1
/Output 14/OUTLED: D71.2 (A), R128.2
/Output 15/OUTBASE: Q18.1 (B), R132.1
/Output 15/OUTLED: D72.2 (A), R131.2
/Output 16/OUTBASE: Q19.1 (B), R135.1
/Output 16/OUTLED: D73.2 (A), R134.2
/Power/3V3REF: C12.2, R10.2, R12.1, U2.5 (FB)
/Power/3V3SW: L3.1, U2.3 (LX)
/Power/5VLED: D6.2 (A), R11.2
/Power/5VMAIN: C4.1, C5.1, D2.2 (A), L1.2, R4.1
/Power/5VRC: C1.1, R1.1
/Power/5VREF: C4.2, R4.2, R5.1, U1.5 (FB)
/Power/5VSH: D2.1 (K), D4.1 (K), R3.2, TP1.1 (1_1)
/Power/5VSW: C1.2, D3.1 (K), L1.1, U1.1 (SW)
/Power/5VUSB: C6.1, C7.1, D4.2 (A), D5.5 (VBUS), J7.A4 (VBUS), J7.A9 (VBUS), J7.B4 (VBUS), J7.B9 (VBUS)
/Power/+24VIN: D1.2 (A), J6.1
/Power/ILIM: R2.2, U1.2 (ILIM), U1.9 (ILIM)
/Power/PHYPWRBJT: Q2.3 (C), R9.1
/Power/PHYPWRFET: C8.2, Q1.1 (G), R8.2, R9.2
/Power/USBCC1: J7.A5 (CC1), R6.1
/Power/USBCC2: J7.B5 (CC2), R7.1
/Power/USBCD+: D5.3 (I/O2), J7.A6 (D+), J7.B6 (D+)
/Power/USBCD-: D5.1 (I/O1), J7.A7 (D-), J7.B7 (D-)
GND: C2.2, C3.2, C5.2, C6.2, C7.2, C9.2, C10.2, C11.2, C13.2, C14.2, C15.2, C16.2, C17.2, C18.2, C19.2, C20.2, C21.2, C22.2, C23.2, C24.2, C25.2, C26.2, C28.2, C30.2, C31.2, C32.2, C33.2, C34.2, C35.2, C36.2, D3.2 (A), D5.2 (GND), D6.1 (K), D7.2 (GND), D8.2 (A), D9.2 (A), J6.2, J7.A1 (GND), J7.A12 (GND), J7.B1 (GND), J7.B12 (GND), J7.S1 (SHIELD), J8.8, J9.3, Q2.2 (E), Q4.2 (E), Q5.2 (E), Q6.2 (E), Q7.2 (E), Q8.2 (E), Q9.2 (E), Q10.2 (E), Q11.2 (E), Q12.2 (E), Q13.2 (E), Q14.2 (E), Q15.2 (E), Q16.2 (E), Q17.2 (E), Q18.2 (E), Q19.2 (E), R5.2, R6.2, R7.2, R12.2, R17.2, R26.1, R27.1, R28.1, R29.2, R32.2, R91.1, R94.1, R97.1, R100.1, R103.1, R106.1, R109.1, R112.1, R115.1, R118.1, R121.1, R124.1, R127.1, R130.1, R133.1, R136.1, SW1.1, TP3.1 (1_1), TP4.1 (1_1), TP5.1 (1_1), U1.4 (GND), U2.2 (GND), U3.2 (GND), U4.3 (GND), U4.11 (GND), U5.1 (GND), U5.15 (GND), U5.38 (GND), U5.39 (GND), U6.24 (TXD2), U6.25 (TXD3), U6.33 (VSS), U7.2 (GND), U8.3 (A2), U8.4 (A1), U8.5 (A0), U8.9 (VSS), U9.3 (A2), U9.4 (A1), U9.9 (VSS), U10.10 (V_{SS}), U10.15 (A0), U10.17 (A2), U11.3 (GND), U11.7 (AD1), U11.8 (AD0), U12.9, U12.11, U12.13, U12.15, U13.9, U13.11, U13.13, U13.15, U14.9, U14.11, U14.13, U14.15, U15.9, U15.11, U15.13, U15.15
GNDIO: C37.2, C38.2, C39.2, C40.2, C41.2, C42.2, C43.2, C44.2, C45.2, C46.2, C47.2, C48.2, C49.2, C50.2, C51.2, C52.2, C53.2, C54.2, C55.2, C56.2, C57.2, C58.2, C59.2, C60.2, C61.2, C62.2, C63.2, C64.2, C65.2, C66.2, C67.2, C68.2, D12.1 (K), D15.1 (K), D18.1 (K), D21.1 (K), D24.1 (K), D27.1 (K), D30.1 (K), D33.1 (K), D36.1 (K), D39.1 (K), D42.1 (K), D45.1 (K), D48.1 (K), D51.1 (K), D54.1 (K), D57.1 (K), J5.1, J5.2, U12.2, U12.4, U12.6, U12.8, U13.2, U13.4, U13.6, U13.8, U14.2, U14.4, U14.6, U14.8, U15.2, U15.4, U15.6, U15.8
unnamed: R1.2, U1.8 (BS)

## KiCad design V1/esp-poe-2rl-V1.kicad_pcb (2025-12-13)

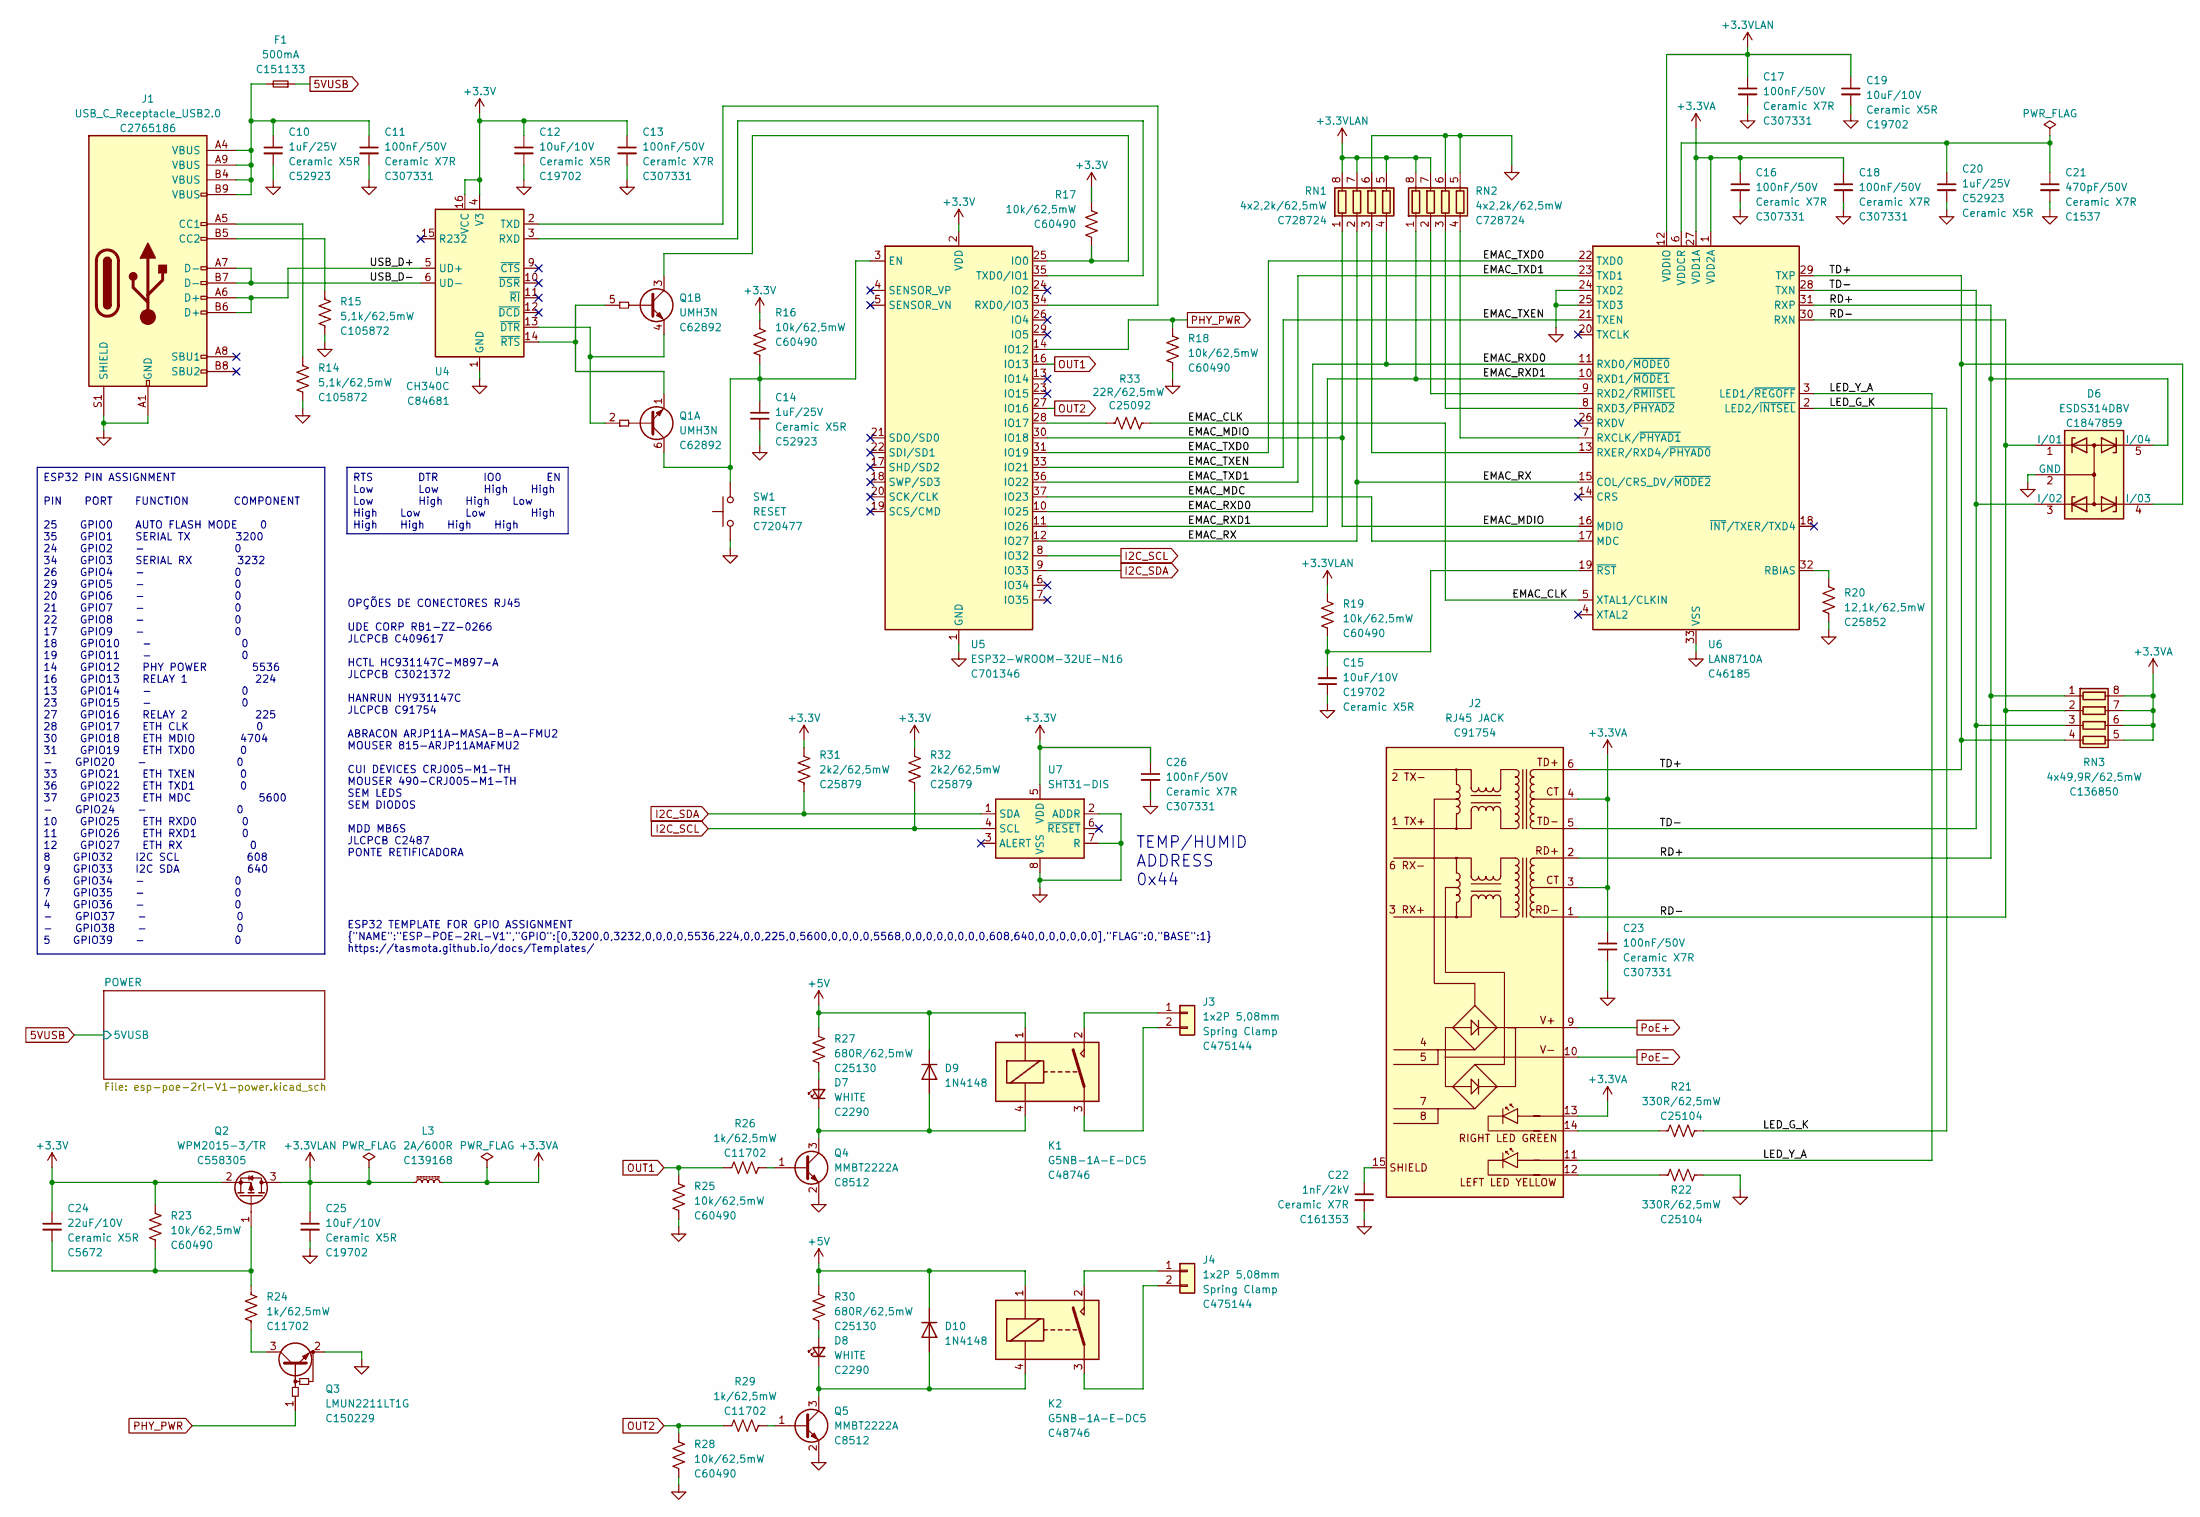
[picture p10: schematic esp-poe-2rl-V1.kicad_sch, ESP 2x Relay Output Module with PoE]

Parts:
C10, C14, C20: 1uF/25V; C_0402_1005Metric; Mfr PN CL05A105KA5NQNC; JLCPCB BOM 1
C11, C13, C16, C17, C18, C23, C26: 100nF/50V; C_0402_1005Metric; Mfr PN CL05B104KB54PNC; JLCPCB BOM 1
C12: 10uF/10V; C_0603_1608Metric; Mfr PN CL10A106KP8NNNC; LCSC Part # C19702
C15, C19, C25: 10uF/10V; C_0603_1608Metric; Mfr PN CL10A106KP8NNNC; JLCPCB BOM 1
C21: 470pF/50V; C_0402_1005Metric; Mfr PN 0402B471K500NT; JLCPCB BOM 1
C22: 1nF/2kV; C_1206_3216Metric; Mfr PN GR431BR7LA102KW66L; JLCPCB BOM 1
C24: 22uF/10V; C_1206_3216Metric; Mfr PN CL31A226KPHNNNE; JLCPCB BOM 1
D6: ESDS314DBV; SOT-23-5; Mfr PN ESDS314DBVR; JLCPCB BOM 1
D7, D8: WHITE; LED_0603_1608Metric; Mfr PN KT-0603W; LCSC Part # C2290
D9, D10: 1N4148; D_SOD-123; Mfr PN 1N4148W; JLCPCB BOM 1
F1: 500mA; Fuse_1206_3216Metric; Mfr PN 0466.500NRHF; JLCPCB BOM 1
J1: USB_C_Receptacle_USB2.0; USB_C_Receptacle_GCT_USB4105-xx-A_16P_TopMnt_Horizontal; Mfr PN TYPE-C 16PIN 2MD(073); JLCPCB BOM 1
J2: RJ45 JACK; RJ45_HanRun_HY931147C; Mfr PN HY931147C; JLCPCB BOM 1
J3, J4: 1x2P 5,08mm; TerminalBlock_Dibo_DB142R-5.08-2P_1x02_P5.08mm_Horizontal; Mfr PN KF142R-5.08-2P; JLCPCB BOM 1
K1, K2: G5NB-1A-E-DC5; Relay_SPST_Omron_G5NB-1A; Mfr PN G5NB-1A-E-DC5; JLCPCB BOM 1
L3: 2A/600R; L_0805_2012Metric; Mfr PN CBM201209U601T; JLCPCB BOM 1
Q1: UMH3N; SOT-363_SC-70-6; Mfr PN UMH3N; JLCPCB BOM 1
Q2: WPM2015-3/TR; SOT-23; Mfr PN WPM2015-3/TR; JLCPCB BOM 1
Q3: LMUN2211LT1G; SOT-23; Mfr PN MMUN2211LT3G; LCSC Part # C150229
Q4, Q5: MMBT2222A; SOT-23; Mfr PN MMBT2222A; JLCPCB BOM 1
R14, R15: 5,1k/62,5mW; R_0402_1005Metric; Mfr PN RC0402FR-075K1L; JLCPCB BOM 1
R16, R17, R18, R19, R23, R25, R28: 10k/62,5mW; R_0402_1005Metric; Mfr PN RC0402FR-0710KL; LCSC Part # C60490
R20: 12,1k/62,5mW; R_0402_1005Metric; Mfr PN 0402WGF1212TCE; JLCPCB BOM 1
R21, R22: 330R/62,5mW; R_0402_1005Metric; Mfr PN 0402WGF3300TCE; LCSC Part # C25104
R24, R26, R29: 1k/62,5mW; R_0402_1005Metric; Mfr PN 0402WGF1001TCE; LCSC Part # C11702
R27, R30: 680R/62,5mW; R_0402_1005Metric; Mfr PN 0402WGF6800TCE; LCSC Part # C25130
R31, R32: 2k2/62,5mW; R_0402_1005Metric; Mfr PN 0402WGF2201TCE; LCSC Part # C25879
R33: 22R/62,5mW; R_0402_1005Metric; Mfr PN 0402WGF220JTCE; JLCPCB BOM 1
RN1, RN2: 4x2,2k/62,5mW; R_Array_Convex_4x0402; Mfr PN YC124-FR-072K2L; JLCPCB BOM 1
RN3: 4x49,9R/62,5mW; R_Array_Convex_4x0402; Mfr PN YC124-FR-0749R9L; JLCPCB BOM 1
SW1: RESET; SW_SPST_Xunpu_TS1088AR02016; Mfr PN TS-1088-AR02016; JLCPCB BOM 1
U4: CH340C; SOIC-16_3.9x9.9mm_P1.27mm; Mfr PN CH340C; JLCPCB BOM 1
U5: ESP32-WROOM-32UE-N16; ESP32-WROOM-32U; Mfr PN ESP32-WROOM-32UE-N16; JLCPCB BOM 1
U6: LAN8710A; QFN-32-1EP_5x5mm_P0.5mm_EP3.3x3.3mm_ThermalVias; Mfr PN LAN8710A-EZC-TR; JLCPCB BOM 1
U7: SHT31-DIS; Sensirion_DFN-8-1EP_2.5x2.5mm_P0.5mm_EP1.1x1.7mm

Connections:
5VUSB: F1.1; also elsewhere on the board
+3.3V: C12.1, C13.1, C24.1, C26.1, Q2.2 (S), R16.1, R17.1, R23.1, R31.1, R32.1, U4.4 (V3), U4.16 (VCC), U5.2 (VDD), U7.5 (VDD); also elsewhere on the board
+3.3VA: C16.1, C18.1, C23.1, J2.3 (CT), J2.4 (CT), J2.13 (RLED+), L3.2, RN3.5 (R4.2), RN3.6 (R3.2), RN3.7 (R2.2), RN3.8 (R1.2), U6.1 (VDD2A), U6.27 (VDD1A)
+3.3VLAN: C17.1, C19.1, C25.1, L3.1, Q2.3 (D), R19.2, RN1.5 (R4.2), RN1.7 (R2.2), RN1.8 (R1.2), RN2.7 (R2.2), RN2.8 (R1.2), U6.12 (VDDIO)
+5V: D9.1 (K), D10.1 (K), K1.1, K2.1, R27.1, R30.1; also elsewhere on the board
/EMAC_CLK: R33.2, U6.5 (XTAL1/CLKIN)
/EMAC_MDC: U5.37 (IO23), U6.17 (MDC)
/EMAC_MDIO: RN1.1 (R1.1), U5.30 (IO18), U6.16 (MDIO)
/EMAC_RX: RN1.2 (R2.1), U5.12 (IO27), U6.15 (COL/CRS_DV/~MODE2)
/EMAC_RXD0: RN1.4 (R4.1), U5.10 (IO25), U6.11 (RXD0/~MODE0)
/EMAC_RXD1: RN2.1 (R1.1), U5.11 (IO26), U6.10 (RXD1/~MODE1)
/EMAC_TXD0: U5.31 (IO19), U6.22 (TXD0)
/EMAC_TXD1: U5.36 (IO22), U6.23 (TXD1)
/EMAC_TXEN: U5.33 (IO21), U6.21 (TXEN)
/LED_G_K: R21.2, U6.2 (LED2/~INTSEL)
/LED_Y_A: J2.11 (LLED+), U6.3 (LED1/~REGOFF)
/RD+: D6.5 (I/04), J2.2 (RD+), RN3.1 (R1.1), U6.31 (RXP)
/RD-: D6.1 (I/01), J2.1 (RD-), RN3.2 (R2.1), U6.30 (RXN)
/TD+: D6.4 (I/03), J2.6 (TD+), RN3.4 (R4.1), U6.29 (TXP)
/TD-: D6.3 (I/02), J2.5 (TD-), RN3.3 (R3.1), U6.28 (TXN)
/USB_D+: J1.A6 (D+), J1.B6 (D+), U4.5 (UD+)
/USB_D-: J1.A7 (D-), J1.B7 (D-), U4.6 (UD-)
GND: C10.2, C11.2, C12.2, C13.2, C14.2, C15.1, C16.2, C17.2, C18.2, C19.2, C20.2, C21.2, C22.2, C23.2, C25.2, C26.2, D6.2 (GND), J1.A1 (GND), J1.A12 (GND), J1.B1 (GND), J1.B12 (GND), J1.S1 (SHIELD), Q3.2 (E), Q4.2 (E), Q5.2 (E), R14.2, R15.2, R18.1, R20.2, R22.2, R25.2, R28.2, RN1.6 (R3.2), RN2.5 (R4.2), RN2.6 (R3.2), SW1.1, U4.1 (GND), U5.1 (GND), U5.15 (GND), U5.38 (GND), U5.39 (GND), U6.24 (TXD2), U6.25 (TXD3), U6.33 (VSS), U7.2 (ADDR), U7.7 (R), U7.8 (VSS), U7.9 (VSS); also elsewhere on the board
I2C_SCL: R32.2, U5.8 (IO32), U7.4 (SCL)
I2C_SDA: R31.2, U5.9 (IO33), U7.1 (SDA)
unnamed: C10.1, C11.1, F1.2, J1.A4 (VBUS), J1.A9 (VBUS), J1.B4 (VBUS), J1.B9 (VBUS)
unnamed: D7.2 (A), R27.2
unnamed: D7.1 (K), D9.2 (A), K1.4, Q4.3 (C)
unnamed: D8.2 (A), R30.2
unnamed: D8.1 (K), D10.2 (A), K2.4, Q5.3 (C)
unnamed: J1.A5 (CC1), R14.1
unnamed: J1.B5 (CC2), R15.1
unnamed: J2.12 (LLED-), R22.1
unnamed: J2.14 (RLED-), R21.1
unnamed: C22.1, J2.15 (SHIELD)
unnamed: J3.1, K1.2
unnamed: J3.2, K1.3
unnamed: J4.1, K2.2
unnamed: J4.2, K2.3
unnamed: Q1.2 (B1), Q1.4 (E2), U4.13 (~DTR)
unnamed: C14.1, Q1.6 (C1), R16.2, SW1.2, U5.3 (EN)
unnamed: Q1.1 (E1), Q1.5 (B2), U4.14 (~RTS)
unnamed: Q1.3 (C2), R17.2, U5.25 (IO0)
unnamed: C24.2, Q2.1 (G), R23.2, R24.1
unnamed: Q3.3 (C), R24.2
unnamed: Q4.1 (B), R26.1
unnamed: Q5.1 (B), R29.1
unnamed: RN1.3 (R3.1), U6.13 (RXER/RXD4/~PHYAD0)
unnamed: RN2.2 (R2.1), U6.9 (RXD2/~RMIISEL)
unnamed: RN2.3 (R3.1), U6.8 (RXD3/~PHYAD2)
unnamed: RN2.4 (R4.1), U6.7 (RXCLK/~PHYAD1)
unnamed: U4.3 (RXD), U5.35 (TXD0/IO1)
unnamed: U4.2 (TXD), U5.34 (RXD0/IO3)
unnamed: R33.1, U5.28 (IO17)
unnamed: R20.1, U6.32 (RBIAS)
unnamed: C20.1, C21.1, U6.6 (VDDCR)
unnamed: C15.2, R19.1, U6.19 (~RST)
OUT1: R25.1, R26.2, U5.16 (IO13)
OUT2: R28.1, R29.2, U5.27 (IO16)
PHY_PWR: Q3.1 (B), R18.2, U5.14 (IO12)
PoE+: J2.9 (V+); also elsewhere on the board
PoE-: J2.10 (V-); also elsewhere on the board

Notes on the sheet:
TEMP/HUMID ADDRESS 0x44
OPÇÕES DE CONECTORES RJ45 UDE CORP RB1-ZZ-0266 JLCPCB C409617 HCTL HC931147C-M897-A JLCPCB C3021372 HANRUN HY931147C JLCPCB C91754 ABRACON ARJP11A-MASA-B-A-FMU2 MOUSER 815-ARJP11AMAFMU2 CUI DEVICES CRJ005-M1-TH MOUSER 490-CRJ005-M1-TH SEM LEDS SEM DIODOS MDD MB6S JLCPCB C2487 PONTE RETIFICADORA
ESP32 TEMPLATE FOR GPIO ASSIGNMENT {"NAME":"ESP-POE-2RL-V1","GPIO":[0,3200,0,3232,0,0,0,0,5536,224,0,0,225,0,5600,0,0,0,0,5568,0,0,0,0,0,0,0,0,608,640,0,0,0,0,0,0],"FLAG":0,"BASE":1} https://tasmota.github.io/docs/Templates/
ESP32 PIN ASSIGNMENT PIN PORT FUNCTION COMPONENT 25 GPIO0 AUTO FLASH MODE 0 35 GPIO1 SERIAL TX 3200 24 GPIO2 - 0 34 GPIO3 SERIAL RX 3232 26 GPIO4 - 0 29 GPIO5 - 0 20 GPIO6 - 0 21 GPIO7 - 0 22 GPIO8 - 0 17 GPIO9 - 0 18 GPIO10 - 0 19 GPIO11 - 0 14 GPIO12 PHY POWER 5536 16 GPIO13 RELAY 1 224 13 GPIO14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
RTS DTR IO0 EN Low Low High High Low High High Low High Low Low High High High High High

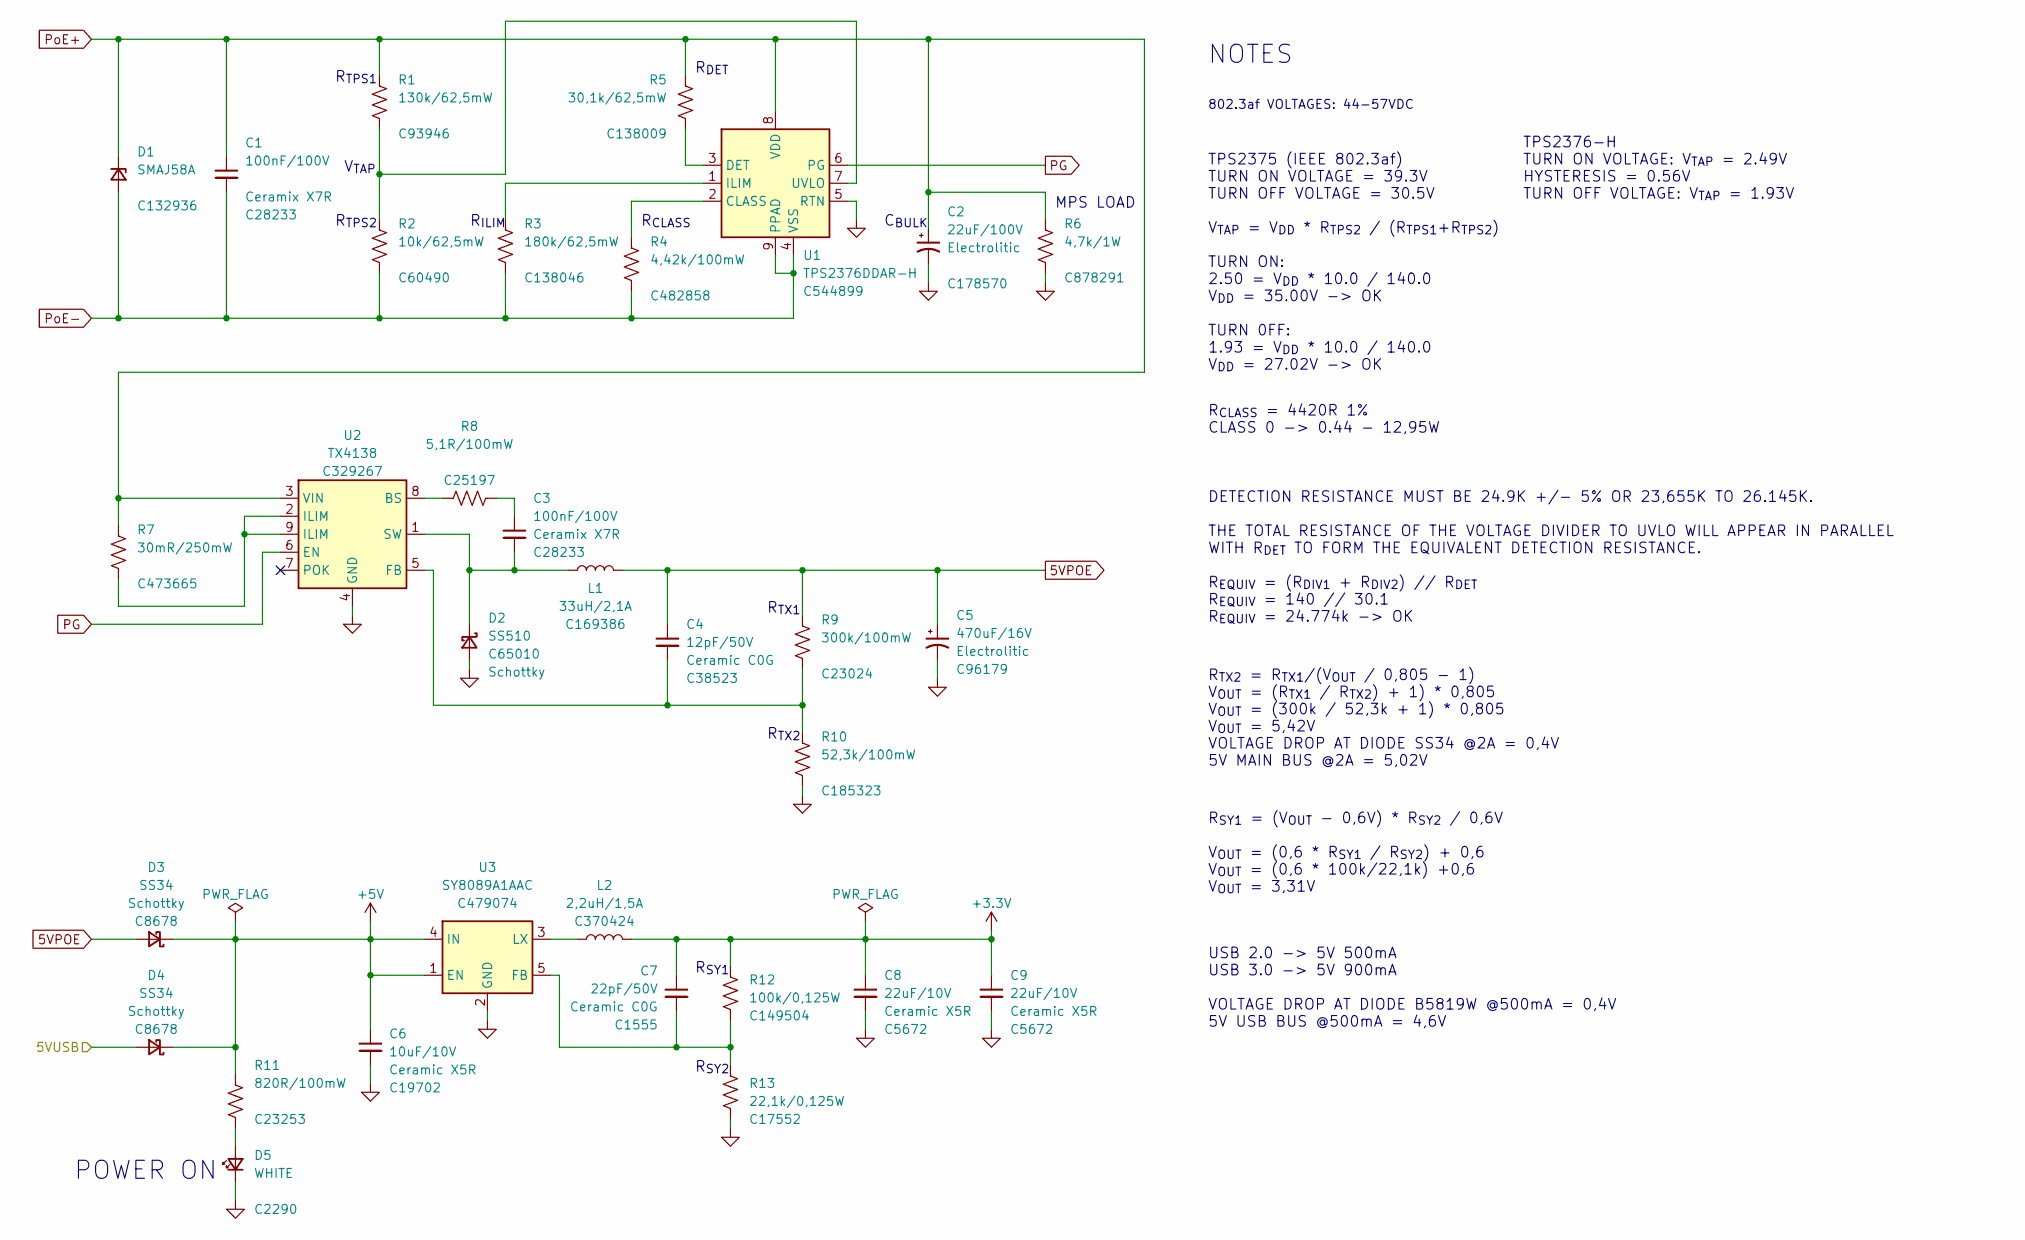
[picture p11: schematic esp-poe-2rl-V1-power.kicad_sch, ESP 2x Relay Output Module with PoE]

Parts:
C1: 100nF/100V; C_0805_2012Metric; Mfr PN CL21B104KCFNNNE; JLCPCB BOM 1
C2: 22uF/100V; CP_Elec_8x10.5; Mfr PN EEEFK2A220P; LCSC Part # C178570
C3: 100nF/100V; C_0805_2012Metric; Mfr PN CL21B104KCFNNNE; LCSC Part # C28233
C4: 12pF/50V; C_0603_1608Metric; Mfr PN CL10C120JB8NNNC; JLCPCB BOM 1
C5: 470uF/16V; CP_Elec_8x10.5; Mfr PN CS1C471M-CRF10; JLCPCB BOM 1
C6: 10uF/10V; C_0603_1608Metric; Mfr PN CL10A106KP8NNNC; JLCPCB BOM 1
C7: 22pF/50V; C_0402_1005Metric; Mfr PN 0402CG220J500NT; JLCPCB BOM 1
C8, C9: 22uF/10V; C_1206_3216Metric; Mfr PN CL31A226KPHNNNE; JLCPCB BOM 1
D1: SMAJ58A; D_SMA; Mfr PN SMAJ58A-TR; JLCPCB BOM 1
D2: SS510; D_SMA; Mfr PN SS510; JLCPCB BOM 1
D3, D4: SS34; D_SMA; Mfr PN SS34; JLCPCB BOM 1
D5: WHITE; LED_0603_1608Metric; Mfr PN KT-0603W; LCSC Part # C2290
L1: 33uH/2,1A; L_12x12mm_h6mm; Mfr PN SWRB1205S-330MT; JLCPCB BOM 1
L2: 2,2uH/1,5A; L_3x3mm_h1.5mm; Mfr PN SPH3015H2R2MT; JLCPCB BOM 1
R1: 130k/62,5mW; R_0402_1005Metric; Mfr PN RC0402FR-07130KL; JLCPCB BOM 1
R2: 10k/62,5mW; R_0402_1005Metric; Mfr PN RC0402FR-0710KL; JLCPCB BOM 1
R3: 180k/62,5mW; R_0402_1005Metric; Mfr PN RC0402FR-07180KL; JLCPCB BOM 1
R4: 4,42k/100mW; R_0603_1608Metric; Mfr PN RC0603FR-074K42L; JLCPCB BOM 1
R5: 30,1k/62,5mW; R_0402_1005Metric; Mfr PN RC0402FR-0730K1L; JLCPCB BOM 1
R6: 4,7k/1W; R_2512_6332Metric; Mfr PN RC2512JK-074K7L; JLCPCB BOM 1
R7: 30mR/250mW; R_1206_3216Metric; Mfr PN 1206W3F300MT5E; LCSC Part # C473665
R8: 5,1R/100mW; R_0603_1608Metric; Mfr PN 0603WAF510KT5E; LCSC Part # C25197
R9: 300k/100mW; R_0603_1608Metric; Mfr PN 0603WAF3003T5E; JLCPCB BOM 1
R10: 52,3k/100mW; R_0603_1608Metric; Mfr PN RC0603FR-0752K3L; JLCPCB BOM 1
R11: 820R/100mW; R_0603_1608Metric; Mfr PN 0603WAF8200T5E; LCSC Part # C23253
R12: 100k/0,125W; R_0805_2012Metric; Mfr PN 0805W8F1003T5E; JLCPCB BOM 1
R13: 22,1k/0,125W; R_0805_2012Metric; Mfr PN 0805W8F2212T5E; JLCPCB BOM 1
U1: TPS2376DDAR-H; SOIC-8-1EP_3.9x4.9mm_P1.27mm_EP2.95x4.9mm_Mask2.71x3.4mm_Th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; Mfr PN TPS2376DDAR-H; JLCPCB BOM 1
U2: TX4138; SOIC-8-1EP_3.9x4.9mm_P1.27mm_EP2.41x3.81mm_ThermalVias; Mfr PN TX4138; JLCPCB BOM 1
U3: SY8089A1AAC; SOT-23-5_Shorter_Pins; Mfr PN SY8089A1AAC; JLCPCB BOM 1

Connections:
5VPOE: C4.1, C5.1, D3.2 (A), L1.2, R9.1
5VUSB: D4.2 (A); also elsewhere on the board
+3.3V: C7.1, C8.1, C9.1, L2.2, R12.1; also elsewhere on the board
+5V: C6.1, D3.1 (K), D4.1 (K), R11.1, U3.1 (EN), U3.4 (IN); also elsewhere on the board
GND: C2.2, C5.2, C6.2, C8.2, C9.2, D2.2 (A), D5.1 (K), R6.2, R10.2, R13.2, U1.5 (RTN), U2.4 (GND), U3.2 (GND); also elsewhere on the board
unnamed: C3.1, R8.1
unnamed: C3.2, D2.1 (K), L1.1, U2.1 (SW)
unnamed: D5.2 (A), R11.2
unnamed: R7.2, U2.2 (ILIM), U2.9 (ILIM)
unnamed: R4.1, U1.2 (CLASS)
unnamed: R5.2, U1.3 (DET)
unnamed: R3.1, U1.1 (ILIM)
unnamed: R1.2, R2.1, U1.7 (UVLO)
unnamed: R8.2, U2.8 (BS)
unnamed: C4.2, R9.2, R10.1, U2.5 (FB)
unnamed: C7.2, R12.2, R13.1, U3.5 (FB)
unnamed: L2.1, U3.3 (LX)
PG: U1.6 (PG), U2.6 (EN)
PoE+: C1.1, C2.1, D1.1 (K), R1.1, R5.1, R6.1, R7.1, U1.8 (VDD), U2.3 (VIN); also elsewhere on the board
PoE-: C1.2, D1.2 (A), R2.2, R3.2, R4.2, U1.4 (VSS), U1.9 (PPAD); also elsewhere on the board

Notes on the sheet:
R_{TPS1}
R_{TX2}
DETECTION RESISTANCE MUST BE 24.9K +/- 5% OR 23,655K TO 26.145K. THE TOTAL RESISTANCE OF THE VOLTAGE DIVIDER TO UVLO WILL APPEAR IN PARALLEL WITH R_{DET} TO FORM THE EQUIVALENT DETECTION RESISTANCE. R_{EQUIV} = (R_{DIV1} + R_{DIV2}) // R_{DET} R_{EQUIV} = 140 // 30.1 R_{EQUIV} = 24.774k -> OK
R_{SY2}
POWER ON
R_{CLASS} = 4420R 1% CLASS 0 -> 0.44 - 12,95W
R_{SY1}
R_{CLASS}
R_{TX2} = R_{TX1}/(V_{OUT} / 0,805 - 1) V_{OUT} = (R_{TX1} / R_{TX2}) + 1) * 0,805 V_{OUT} = (300k / 52,3k + 1) * 0,805 V_{OUT} = 5,42V VOLTAGE DROP AT DIODE SS34 @2A = 0,4V 5V MAIN BUS @2A = 5,02V
C_{BULK}
R_{ILIM}
USB 2.0 -> 5V 500mA USB 3.0 -> 5V 900mA VOLTAGE DROP AT DIODE B5819W @500mA = 0,4V 5V USB BUS @500mA = 4,6V
TPS2375 (IEEE 802.3af) TURN ON VOLTAGE = 39.3V TURN OFF VOLTAGE = 30.5V
V_{TAP}
TPS2376-H TURN ON VOLTAGE: V_{TAP} = 2.49V HYSTERESIS = 0.56V TURN OFF VOLTAGE: V_{TAP} = 1.93V
R_{SY1} = (V_{OUT} - 0,6V) * R_{SY2} / 0,6V V_{OUT} = (0,6 * R_{SY1} / R_{SY2}) + 0,6 V_{OUT} = (0,6 * 100k/22,1k) +0,6 V_{OUT} = 3,31V
R_{TPS2}
R_{TX1}
NOTES
MPS LOAD
R_{DET}
802.3af VOLTAGES: 44-57VDC
V_{TAP} = V_{DD} * R_{TPS2} / (R_{TPS1}+R_{TPS2}) TURN ON: 2.50 = V_{DD} * 10.0 / 140.0 V_{DD} = 35.00V -> OK TURN 0FF: 1.93 = V_{DD} * 10.0 / 140.0 V_{DD} = 27.02V -> OK

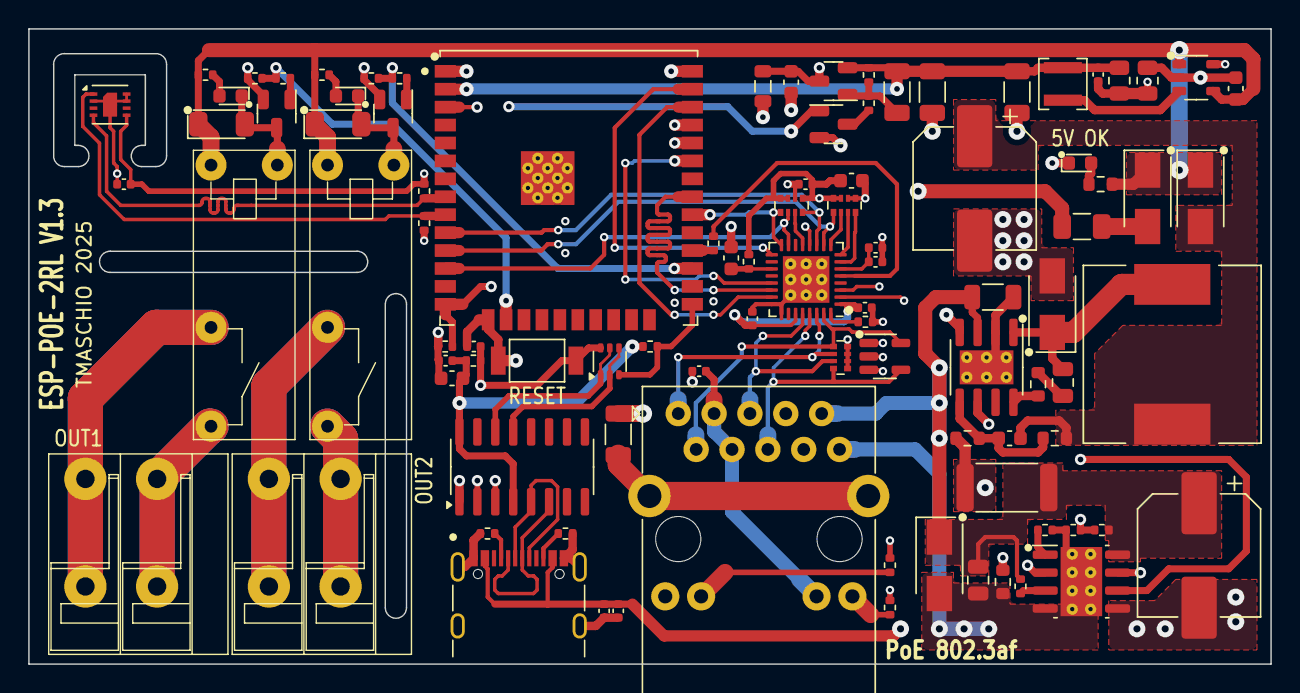
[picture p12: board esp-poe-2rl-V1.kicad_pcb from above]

Board: 4 copper layers, 88.0 x 45.0 mm, 95 parts (0 on the bottom side), 76 nets.

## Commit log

2025-12-13 Deleted unused files
    [bom.csv, designators.csv, esp-poe-2rl-V1-CaixaBase.step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]
2025-12-19 dev time
    [esp-poe-010v-V1-power.kicad_sch, esp-poe-010v-V1.kicad_pcb, esp-poe-010v-V1.kicad_sch]
2026-06-18 Starting for an existing project.
    [esp-poe-010v-V1-power.kicad_sch, esp-poe-010v-V1.kicad_pcb, esp-poe-010v-V1.kicad_sch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]
2026-06-18 Renamed all files to reflect the eumesmo branding.
    [eumesmo-010-16ch-v1-i2c.kicad_sch, eumesmo-010-16ch-v1-lan.kicad_sch, eumesmo-010-16ch-v1-mcu.kicad_sch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]
2026-06-18 Restarting fresh
    [eumesmo-010-16ch-v1-i2c.kicad_sch, eumesmo-010-16ch-v1-mcu.kicad_sch, eumesmo-010-16ch-v1-power.kicad_sch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]
2026-06-24 Rename project from ESP-POE-010V to eumesmo-010-16ch
2026-06-27 Power and heartbeat leds repositioned.
    [eumesmo-010-16ch-v1.kicad_pcb, positions.csv]
2026-07-04 Added CPU health LED
    [eumesmo-010-16ch-v1.kicad_pcb]
2026-07-10 Adjusted components according to availability in JLCPCB.
    [bom.csv, eumesmo-010-16ch-analogs.kicad_sch, eumesmo-010-16ch-v1-i2c.kicad_sch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]
2026-07-10 Adjusted the footprint for the reset switch.
    [eumesmo-010-16ch-v1.kicad_pcb]
2026-08-28 Text translated to english
    [bom.csv, eumesmo-010-16ch-v1-i2c.kicad_sch, eumesmo-010-16ch-v1-lan.kicad_sch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]
2026-09-22 RJ45 jack and terminal blocks repositioned
    RJ45 jack and terminal blocks repositioned inwards the board to make space for the PCB holder. ETH tracks rerouted for better EMC.
    [bom.csv, designators.csv, eumesmo-010-16ch-v1-power.kicad_sch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]
2026-09-23 Adjusted day of last modification
    [eumesmo-010-16ch-analogs.kicad_sch, eumesmo-010-16ch-v1-i2c.kicad_sch, eumesmo-010-16ch-v1-lan.kicad_sch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]
2026-09-24 Change LEDs for orange
    [bom.csv, eumesmo-010-16ch-v1-i2c.kicad_sch, eumesmo-010-16ch-v1-mcu.kicad_sch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]
2026-10-07 Component rotations and offsets ajusted for JLCPCB
    [bom.csv, eumesmo-010-16ch-v1-i2c.kicad_sch, eumesmo-010-16ch-v1-lan.kicad_sch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]
